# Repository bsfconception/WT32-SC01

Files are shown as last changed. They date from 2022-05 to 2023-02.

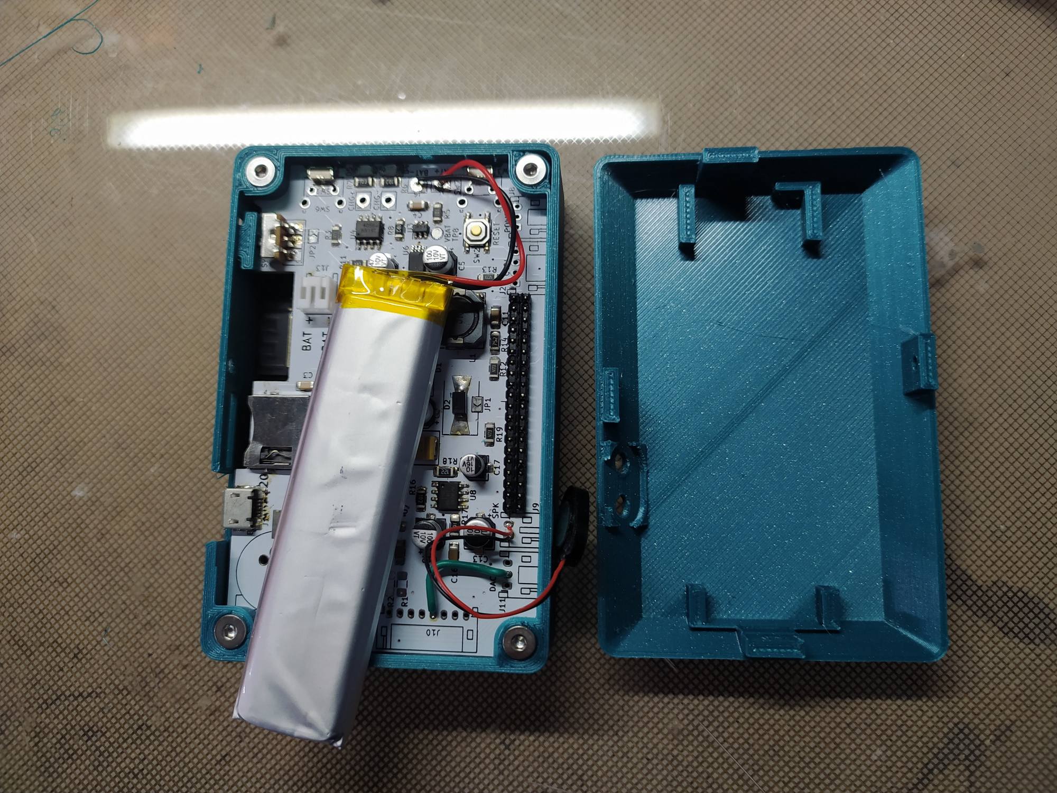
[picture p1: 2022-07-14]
Cases/V1.1/Image1.jpg

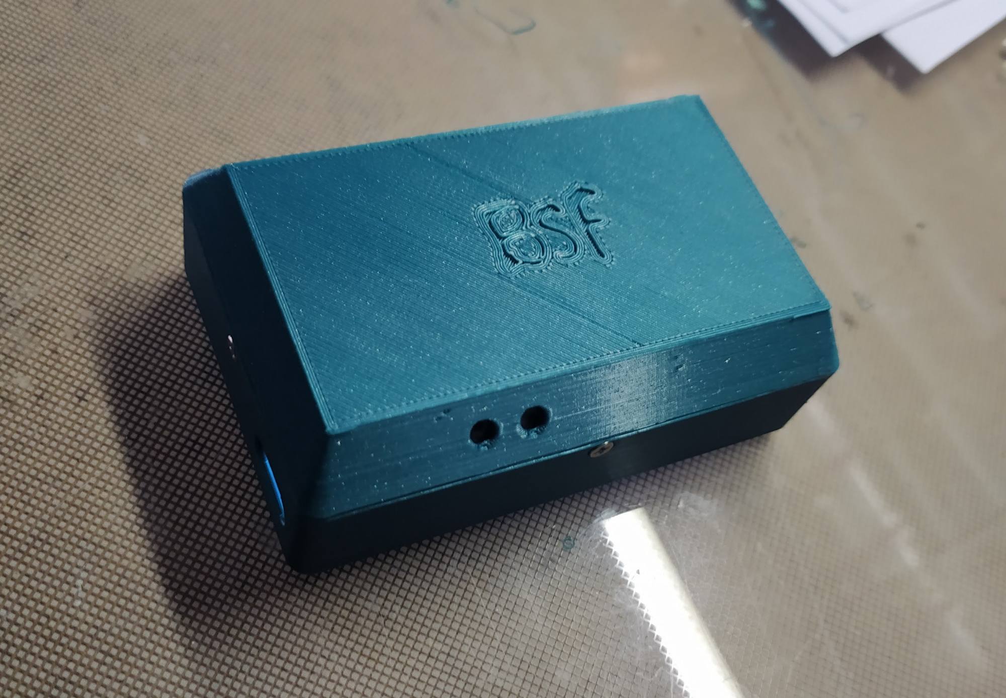
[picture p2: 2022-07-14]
Cases/V1.1/Image2.jpg

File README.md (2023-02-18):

# WT32-SC01 Extension Board V2.0

## Extension board for the WT32-SC01 Dev Kit

this board is ready to be plugged one of the WT32-SC01 from Wireless-Tag (c)
http://www.wireless-tag.com/portfolio/wt32-sc01/

It includes the following features:
- New LiPo - LiIon battery charger with overcharge and overdischarge protection
- 4 power status LEDs (0 to 100%)
- 2 push buttons with sleep and deep sleep capabilities
- DS3121M - DS3231 - PCF8563T RTC clock + backup battery - SuperCapa
- Micro SD connector
- MCP4725 DAC + LM386 Speaker amplifier 
- I2C, IO, Control and Power extension connectors
- MicroUSB connector for Li-Ion charging 
- Buzzer

The last current version is V2.0

The manufactiring files are avialable here : https://github.com/bsfconception/WT32-SC01/tree/main/Versions/V2.0
3D_CAPA

PinOut

WT32-SC01-Layout

## Demo Source Code

The demo source code tests all the expansion board feature. The testing code is provided "as is" and includes : 
- DAC setup and test
- Basic GUI with buttons and actions control
- I2C scanner
- JPEG decoder and display
- SD Card files acces control
- SPIFF files acces control
- RTC management
- Web Server with WiFi settings and control
- ...

Note : check the code to mofidy and adjust for your testing. The "Display Picture" feature loads by defaut "logo.jpg" from the SD Card
The source code is provided "as is" as an example. Some adjustments may be required in your configuration to compile

These measurements are performed using the provided test code.

## Li-Ion battery Charging Note
The battery cna be charged from several power sources
- Micro USB Connector
- Wireless IQ module
- external power plug

The WT32-SC01 USBC-C connector CANNOT be used to charge the Li-Ion battery.

### Important Notice : Power OFF the on board power supply during the programming

# Change History
- V1.0 : 
  - correction of the Beta V0.9 (bad connector positon)
- V1.1 : 
  - Micro USB connector for battery charging
  - SEL button option selection (Pull-Up or Down)
- V1.2 : 
  - Power led on the PCB
  - RF Emitter footprint
  - DS1307 footprint (less accurate, but less expensive)
  - Jumper between ESP32 pin and Audio Amp
- V2.0 : 
  - New Li-Ion charger + Bulk Power 
  - Support DS3231 - PCF8563T
  - Super Capacitor (RTC backup)
  - On Board Buzzer
  - Merge of the 2 "audio" connectors

## You want a PCB ?
You can either bluid your own with the provided manufactiring files, or purchase here :
#NOTE : the previous version are not more available. The new vervion (V2.0) is in production.

PCB Only : https://www.tindie.com/products/28469/

Assembled board : https://www.tindie.com/products/26898/



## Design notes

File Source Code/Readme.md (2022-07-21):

# Demonstration Software

The demo code is provided "as is". Is is based on personal developement and from examples retrived from sereval sources.

The intend of this software is to check the operation of the board, NOT TO PROVIDE A FINAL SOLUTION. 

## Arduino Configuration
- Version 1.8.19
- Boards Manager in "preferences":
    - https://raw.githubusercontent.com/espressif/arduino-esp32/gh-pages/package_esp32_index.json
    - http://arduino.esp8266.com/stable/package_esp8266com_index.json

## Some libraries are required to compile the code:

- name=Adafruit BusIO       url=https://github.com/adafruit/Adafruit_BusIO	        version=1.12.0
- name=Adafruit FT6206 Library      url=https://github.com/adafruit/Adafruit_FT6206_Library	        version=1.0.6
- name=Adafruit GFX Library     	url=https://github.com/adafruit/Adafruit-GFX-Library	        version=1.11.3
- name=Adafruit ILI9341	        url=https://github.com/adafruit/Adafruit_ILI9341	        version=1.5.11
- name=JPEGDecoder	        url=https://github.com/Bodmer/JPEGDecoder	        version=1.8.1
- name=lvgl	        url=https://lvgl.io	        version=8.2.0
- name=MCP4725	        url=https://github.com/RobTillaart/MCP4725	    version=0.3.3
- name=RTClib	        url=https://github.com/adafruit/RTClib	        version=2.0.3
- name=TFT_eSPI	        url=https://github.com/Bodmer/TFT_eSPI	        version=2.4.72

# Libraries customisation

Sereval modification are requied in the downloaded libraries:

## TFT_eSPI library 
has to be correctly setup for the destination board during compiling : 
A configuration file has to be created and stored in the LIB folder
C:\Users\xxxuserxxx\Documents\Arduino\libraries\TFT_eSPI
- User_Setup_Select.h
- WT32-SC01-User_Setup.h

## LVGL
the following file 
    C:\Users\XXXX\Documents\Arduino\libraries\lvgl\lv_conf_template.h
    must be renamed and copied to 
    C:\Users\XXXX\Documents\Arduino\libraries\lvgl\src\lv_conf.h

# Test code 
Two examples are provided : 
- WT32_BSF_LVGL_Demo : code based on the previous but adding the LVGL graphical interface. A setting enables or disables the LVGL features

Ensure that you enable the SPIFF features when compiling and uploading the code on the ESP32

## Notes
Somes guides have been helpfull to make it run
- https://blog.csdn.net/weixin_44007534/article/details/115224595
- https://daumemo.com/how-to-use-lvgl-library-on-arduino-with-an-esp-32-and-spi-lcd/
- https://github.com/sukesh-ak/LVGL8-WT32-SC01-Arduino

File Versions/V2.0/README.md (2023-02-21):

# WT32-SC01 Extension Board V2.0

## Extension board for the WT32-SC01 Dev Kit

this board is ready to be plugged one of the WT32-SC01 from Wireless-Tag (c)
http://www.wireless-tag.com/portfolio/wt32-sc01/

It includes the following features:
- New LiPo - LiIon battery charger with overcharge and overdischarge protection
- 4 power status LEDs (0 to 100%)
- 2 push buttons with sleep and deep sleep capabilities
- DS3121M - DS3231 - PCF8563T RTC clock + backup battery - SuperCapa
- Micro SD connector
- MCP4725 DAC + LM386 Speaker amplifier 
- I2C, IO, Control and Power extension connectors
- MicroUSB connector for Li-Ion charging 
- Buzzer

The last current version is V2.0

The manufactiring files are avialable here : https://github.com/bsfconception/WT32-SC01/tree/main/Versions/V2.0
3D_CAPA

PinOut

WT32-SC01-Layout

## Note about he IP5306 Integrated Power Bank SOC
The datasheet contains an error about the usage of the POWER key : 
- Short Pulse : POWER ON
- 2 Short Pulses : POWER OFF
- Long Pulse (>2sec) : Toggle Torch Light

## Demo Source Code

The demo source code tests all the expansion board feature. The testing code is provided "as is" and includes : 
- DAC setup and test
- IO4 PMW output if NO DEC is present
- Basic GUI with buttons and actions control
- I2C scanner
- JPEG decoder and display
- SD Card files acces control
- SPIFF files acces control
- DS3231 / DS3232 / PCF8563 RTC chip management
- Web Server with WiFi settings and control
- ...

Note : check the code to mofidy and adjust for your testing. The "Display Picture" feature loads by defaut "logo.jpg" from the SD Card
The source code is provided "as is" as an example. Some adjustments may be required in your configuration to compile

These measurements are performed using the provided test code.

## Li-Ion battery Charging Note
The battery cna be charged from several power sources
- Micro USB Connector
- Wireless IQ module
- external power plug

The WT32-SC01 USBC-C connector CANNOT be used to charge the Li-Ion battery.

### Important Notice : Power OFF the on board power supply during the programming

# Change History
- V1.0 : 
  - correction of the Beta V0.9 (bad connector positon)
- V1.1 : 
  - Micro USB connector for battery charging
  - SEL button option selection (Pull-Up or Down)
- V1.2 : 
  - Power led on the PCB
  - RF Emitter footprint
  - DS1307 footprint (less accurate, but less expensive)
  - Jumper between ESP32 pin and Audio Amp
- V2.0 : 
  - New Li-Ion charger + Bulk Power 
  - Support DS3231 - PCF8563T
  - Super Capacitor (RTC backup)
  - On Board Buzzer
  - Merge of the 2 "audio" connectors

## You want a PCB ?
You can either bluid your own with the provided manufactiring files, or purchase here :
#NOTE : the previous version are not more available. The new vervion (V2.0) is in production.

PCB Only : https://www.tindie.com/products/28469/

Assembled board : https://www.tindie.com/products/26898/



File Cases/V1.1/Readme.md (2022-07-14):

New example of 3D printed enclosure for the WT32-SC01 + Extension Board






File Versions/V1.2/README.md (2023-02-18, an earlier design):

# WT32-SC01 Extension Board V1.2

## Extension board for the WT32-SC01 Dev Kit

this board is ready to be plugged one of the WT32-SC01 from Wireless-Tag (c)
http://www.wireless-tag.com/portfolio/wt32-sc01/

It includes the following features:
- LiPo - LiIon battery charger with overcharge and overdischarge protection
- Charging status LEDs
- 2 push buttons with sleep and deep sleep capabilities
- DS3121M RTC clock + backup battery (OR)
- DS1307 + Crystal + backup battery
- Micro SD connector
- MCP4725 DAC + LM386 Speaker amplifier 
- I2C, IO, Control and Power extension connectors
- Battery Voltage feedback to the ESP
- MicroUSB connector for Li-Ion charging 
- Power LED (Note : the 5V power LED is lightned only when the WT32 SC01 main board is plugged on)
- RF Transmitter 3 pins connector

View

PCB Pinout 
WT32-SC01 Pinout_Red

PCB Assembly
WT32-SC01 V1 2_Assembly

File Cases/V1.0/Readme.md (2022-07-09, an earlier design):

You'll find here a example of 3D printed box and holder to insert the WT32

Below some illustration of the mounting and results : 

Solter 3mm inserts on the WT32 main PCB :


3D printed box :


Assembling the wirelass charger:


Adding the 1500mAh LiIon battery:




Testing the charger


The Holder 3D view (Laser cut acrylic sheet)

WT32_SC01_V0

The SVG file is provided as well in the "Holder" folder

The Wireless charger is based on these modules :
H4e3d569b123046619c432bc34786523bI
and 
H26b5287e51b44ef6bf7de7b725d772dfk
Available also on AliExpress

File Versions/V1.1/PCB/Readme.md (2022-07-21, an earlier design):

# Jumpers Options

## JP3 : set the MCP4725 address
According to the soldered bridge, the I2C addresse will change.

Jumper1

This example may change according to the manufacturer's specifications

## JP4 : SEL button default value

- Configuration 1 (default) : the Default value for SEL is '0'

R19 Set

Jumper2_0

- Configuration 2  : the Default value for SEL is '1'

R19 Remove

Jumper2_1

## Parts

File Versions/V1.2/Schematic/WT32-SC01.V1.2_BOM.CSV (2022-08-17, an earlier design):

Reference(s) | Value | Footprint
BT1 | CR1220 | Livrary:CR1220_SMD
C1 | 100nF | Capacitor_SMD:C_1206_3216Metric_Pad1.42x1.75mm_HandSolder
C2 | 10uF | Capacitor_SMD:CP_Elec_4x4.5
C3 | 100nF | Capacitor_SMD:C_1206_3216Metric_Pad1.42x1.75mm_HandSolder
C4 | 100nF | Capacitor_SMD:C_1206_3216Metric_Pad1.42x1.75mm_HandSolder
C5 | 100uF | Capacitor_SMD:CP_Elec_5x5.3
C6 | 470uF | Capacitor_Tantalum_SMD:CP_EIA-7360-38_Kemet-E
C7 | 100uF | Capacitor_SMD:CP_Elec_5x5.3
C8 | 100uF | Capacitor_SMD:CP_Elec_5x5.3
C9 | 470uF | Capacitor_Tantalum_SMD:CP_EIA-7360-38_Kemet-E
C10 | 47uF | Capacitor_SMD:CP_Elec_4x4.5
C11 | 100nF | Capacitor_SMD:C_1206_3216Metric_Pad1.42x1.75mm_HandSolder
C12 | 100uF | Capacitor_SMD:CP_Elec_5x5.3
C13 | 220uF | Capacitor_SMD:CP_Elec_5x5.3
C14 | 100nF | Capacitor_SMD:C_1206_3216Metric_Pad1.42x1.75mm_HandSolder
C15 | 220uF | Capacitor_SMD:CP_Elec_5x5.3
C16 | 47nF | Capacitor_SMD:C_1206_3216Metric_Pad1.42x1.75mm_HandSolder
C17 | 10uF | Capacitor_SMD:CP_Elec_4x4.5
C18 | 220uF | Capacitor_Tantalum_SMD:CP_EIA-7360-38_Kemet-E_Pad2.25x4.25mm_HandSolder
C19 | 100nF | Capacitor_SMD:C_1206_3216Metric_Pad1.42x1.75mm_HandSolder
D1 | SR540 | Diode_SMD:D_SMA
D2 | 1N4004 | Diode_SMD:D_SMA
D3 | PWR | LED_SMD:LED_1206_3216Metric_Pad1.42x1.75mm_HandSolder
D4 | STBY | LED_SMD:LED_1206_3216Metric_Pad1.42x1.75mm_HandSolder
D5 | CHRG | LED_SMD:LED_1206_3216Metric_Pad1.42x1.75mm_HandSolder
J1 | SD_Card | Livrary:TF_SDCard
J2 | CTRL | Connector_JST:JST_PH_S4B-PH-K_1x04_P2.00mm_Horizontal
J3 | I2C | Connector_JST:JST_PH_S4B-PH-K_1x04_P2.00mm_Horizontal
J8 | POWER | Connector_JST:JST_PH_S3B-PH-K_1x03_P2.00mm_Horizontal
J9 | SPK | Connector_JST:JST_PH_S2B-PH-K_1x02_P2.00mm_Horizontal
J10 | GPIO | Connector_JST:JST_PH_S8B-PH-K_1x08_P2.00mm_Horizontal
J11 | DAC | Connector_JST:JST_PH_S3B-PH-K_1x03_P2.00mm_Horizontal
J12 | I2C | Connector_JST:JST_SH_SM04B-SRSS-TB_1x04-1MP_P1.00mm_Horizontal
J13 | BAT | Connector_JST:JST_PH_S2B-PH-K_1x02_P2.00mm_Horizontal
J14 | USB_B_Micro | Livrary:USB_Micro-B
L1 | 3u3 | Inductor_SMD:L_10.4x10.4_H4.8
R1 | 47K* - NOT REQUIRED | Resistor_SMD:R_1206_3216Metric_Pad1.42x1.75mm_HandSolder
R2 | 47K* - NOT REQUIRED | Resistor_SMD:R_1206_3216Metric_Pad1.42x1.75mm_HandSolder
R3 | 47K | Resistor_SMD:R_1206_3216Metric_Pad1.42x1.75mm_HandSolder
R4 | 75K | Resistor_SMD:R_1206_3216Metric_Pad1.42x1.75mm_HandSolder
R5 | 100 | Resistor_SMD:R_1206_3216Metric_Pad1.42x1.75mm_HandSolder
R6 | 1K | Resistor_SMD:R_1206_3216Metric_Pad1.42x1.75mm_HandSolder
R7 | 1K | Resistor_SMD:R_1206_3216Metric_Pad1.42x1.75mm_HandSolder
R8 | 1K | Resistor_SMD:R_1206_3216Metric_Pad1.42x1.75mm_HandSolder
R9 | 10K | Resistor_SMD:R_1206_3216Metric_Pad1.42x1.75mm_HandSolder
R10 | 33K | Resistor_SMD:R_1206_3216Metric_Pad1.42x1.75mm_HandSolder
R11 | 1K8 | Resistor_SMD:R_1206_3216Metric_Pad1.42x1.75mm_HandSolder
R12 | 47K | Resistor_SMD:R_1206_3216Metric_Pad1.42x1.75mm_HandSolder
R13 | 47K | Resistor_SMD:R_1206_3216Metric_Pad1.42x1.75mm_HandSolder
R14 | 7K5 | Resistor_SMD:R_1206_3216Metric_Pad1.42x1.75mm_HandSolder
R15 | 20K | Resistor_SMD:R_1206_3216Metric_Pad1.42x1.75mm_HandSolder
R16 | 1K | Resistor_SMD:R_1206_3216Metric_Pad1.42x1.75mm_HandSolder
R17 | 10 | Resistor_SMD:R_1206_3216Metric_Pad1.42x1.75mm_HandSolder
R18 | 1K2 | Resistor_SMD:R_1206_3216Metric_Pad1.42x1.75mm_HandSolder
R19 | 47K | Resistor_SMD:R_1206_3216Metric_Pad1.42x1.75mm_HandSolder
R20 | 1K | Resistor_SMD:R_1206_3216Metric_Pad1.42x1.75mm_HandSolder
R21 | 10K | Resistor_SMD:R_1206_3216Metric_Pad1.42x1.75mm_HandSolder
SW1 | WAKE | Livrary:SW_PUSH_TS_1224W
SW2 | RESET | Livrary:SW_Push_1P1T_Mini4x4x1.5
SW3 | SEL | Livrary:SW_PUSH_TS_1224W
SW4 | SWITCH | Livrary:SW_MSK_01S
SW5 | SWITCH | Livrary:SPDT_Small
SW6 | WAKE | Button_Switch_THT:SW_Tactile_SPST_Angled_PTS645Vx58-2LFS
SW7 | SEL | Button_Switch_THT:SW_Tactile_SPST_Angled_PTS645Vx58-2LFS
U1 | DS3231M | Package_SO:SOIC-16W_7.5x10.3mm_P1.27mm
U2 | WT32-SC01 | Livrary:WS32-SC01-H
U3 | DW01x | Package_TO_SOT_SMD:TSOT-23-6
U4 | TP4056 | Livrary:SOP-8_EP
U5 | FP6298 | Package_SO:SOIC-8-1EP_3.9x4.9mm_P1.27mm_EP2.29x3mm
U6 | FS8205 | Package_SO:TSSOP-8_4.4x3mm_P0.65mm
U7 | MCP4725-DAC7571 | Package_TO_SOT_SMD:SOT-23-6
U8 | LM386 | Package_SO:SOIC-8_3.9x4.9mm_P1.27mm
U9 | TX | Livrary:TX50
U10 | DS1307Z+ | Package_SO:SOIC-8_3.9x4.9mm_P1.27mm
Y1 | 32KHz | Crystal:Crystal_C26-LF_D2.1mm_L6.5mm_Horizontal_1EP_style2
Collated Components:
Qty | Reference(s) | Value | Footprint
1 | BT1 | CR1220 | Livrary:CR1220_SMD
6 | C1, C3, C4, C11, C14, C19 | 100nF | Capacitor_SMD:C_1206_3216Metric_Pad1.42x1.75mm_HandSolder
2 | C2, C17 | 10uF | Capacitor_SMD:CP_Elec_4x4.5
6 | C5, C7, C8, C12,C13, C15 | 100uF | Capacitor_SMD:CP_Elec_5x5.3
3 | C6, C9,C18 | 470uF | Capacitor_Tantalum_SMD:CP_EIA-7360-38_Kemet-E
1 | C10 | 47uF | Capacitor_SMD:CP_Elec_4x4.5
1 | C16 | 47nF | Capacitor_SMD:C_1206_3216Metric_Pad1.42x1.75mm_HandSolder
1 | D1 | SR540 | Diode_SMD:D_SMA
1 | D2 | 1N4004 | Diode_SMD:D_SMA
1 | D3 | PWR | LED_SMD:LED_1206_3216Metric_Pad1.42x1.75mm_HandSolder
1 | D4 | STBY | LED_SMD:LED_1206_3216Metric_Pad1.42x1.75mm_HandSolder
1 | D5 | CHRG | LED_SMD:LED_1206_3216Metric_Pad1.42x1.75mm_HandSolder
1 | J1 | SD_Card | Livrary:TF_SDCard
1 | J2 | CTRL | Connector_JST:JST_PH_S4B-PH-K_1x04_P2.00mm_Horizontal
1 | J3 | I2C | Connector_JST:JST_PH_S4B-PH-K_1x04_P2.00mm_Horizontal
1 | J8 | POWER | Connector_JST:JST_PH_S3B-PH-K_1x03_P2.00mm_Horizontal
1 | J9 | SPK | Connector_JST:JST_PH_S2B-PH-K_1x02_P2.00mm_Horizontal
1 | J10 | GPIO | Connector_JST:JST_PH_S8B-PH-K_1x08_P2.00mm_Horizontal
1 | J11 | DAC | Connector_JST:JST_PH_S3B-PH-K_1x03_P2.00mm_Horizontal
1 | J12 | I2C | Connector_JST:JST_SH_SM04B-SRSS-TB_1x04-1MP_P1.00mm_Horizontal
1 | J13 | BAT | Connector_JST:JST_PH_S2B-PH-K_1x02_P2.00mm_Horizontal
1 | J14 | USB_B_Micro | Livrary:USB_Micro-B
1 | L1 | 3u3 | Inductor_SMD:L_10.4x10.4_H4.8
2 | R1, R2 - NOT REQUIRED | 47K* | Resistor_SMD:R_1206_3216Metric_Pad1.42x1.75mm_HandSolder
4 | R3, R12, R13, R19 | 47K | Resistor_SMD:R_1206_3216Metric_Pad1.42x1.75mm_HandSolder
1 | R4 | 75K | Resistor_SMD:R_1206_3216Metric_Pad1.42x1.75mm_HandSolder
1 | R5 | 100 | Resistor_SMD:R_1206_3216Metric_Pad1.42x1.75mm_HandSolder
5 | R6, R7, R8, R16, R20 | 1K | Resistor_SMD:R_1206_3216Metric_Pad1.42x1.75mm_HandSolder
2 | R9, R21 | 10K | Resistor_SMD:R_1206_3216Metric_Pad1.42x1.75mm_HandSolder
1 | R10 | 33K | Resistor_SMD:R_1206_3216Metric_Pad1.42x1.75mm_HandSolder
1 | R11 | 1K8 | Resistor_SMD:R_1206_3216Metric_Pad1.42x1.75mm_HandSolder
1 | R14 | 7K5 | Resistor_SMD:R_1206_3216Metric_Pad1.42x1.75mm_HandSolder
1 | R15 | 20K | Resistor_SMD:R_1206_3216Metric_Pad1.42x1.75mm_HandSolder
1 | R17 | 10 | Resistor_SMD:R_1206_3216Metric_Pad1.42x1.75mm_HandSolder
1 | R18 | 1K2 | Resistor_SMD:R_1206_3216Metric_Pad1.42x1.75mm_HandSolder
1 | SW1 | WAKE | Livrary:SW_PUSH_TS_1224W
1 | SW2 | RESET | Livrary:SW_Push_1P1T_Mini4x4x1.5
1 | SW3 | SEL | Livrary:SW_PUSH_TS_1224W
1 | SW4 | SWITCH | Livrary:SW_MSK_01S
1 | SW5 | SWITCH | Livrary:SPDT_Small
1 | SW6 | WAKE | Button_Switch_THT:SW_Tactile_SPST_Angled_PTS645Vx58-2LFS
1 | SW7 | SEL | Button_Switch_THT:SW_Tactile_SPST_Angled_PTS645Vx58-2LFS
1 | U1 | DS3231M | Package_SO:SOIC-16W_7.5x10.3mm_P1.27mm
1 | U2 | WT32-SC01 | Livrary:WS32-SC01-H
1 | U3 | DW01x | Package_TO_SOT_SMD:TSOT-23-6
1 | U4 | TP4056 | Livrary:SOP-8_EP
1 | U5 | FP6298 | Package_SO:SOIC-8-1EP_3.9x4.9mm_P1.27mm_EP2.29x3mm
1 | U6 | FS8205 | Package_SO:TSSOP-8_4.4x3mm_P0.65mm
1 | U7 | MCP4725-DAC7571 | Package_TO_SOT_SMD:SOT-23-6
1 | U8 | LM386 | Package_SO:SOIC-8_3.9x4.9mm_P1.27mm
1 | U9 | TX | Livrary:TX50
1 | U10 | DS1307Z+ | Package_SO:SOIC-8_3.9x4.9mm_P1.27mm
1 | Y1 | 32KHz | Crystal:Crystal_C26-LF_D2.1mm_L6.5mm_Horizontal_1EP_style2

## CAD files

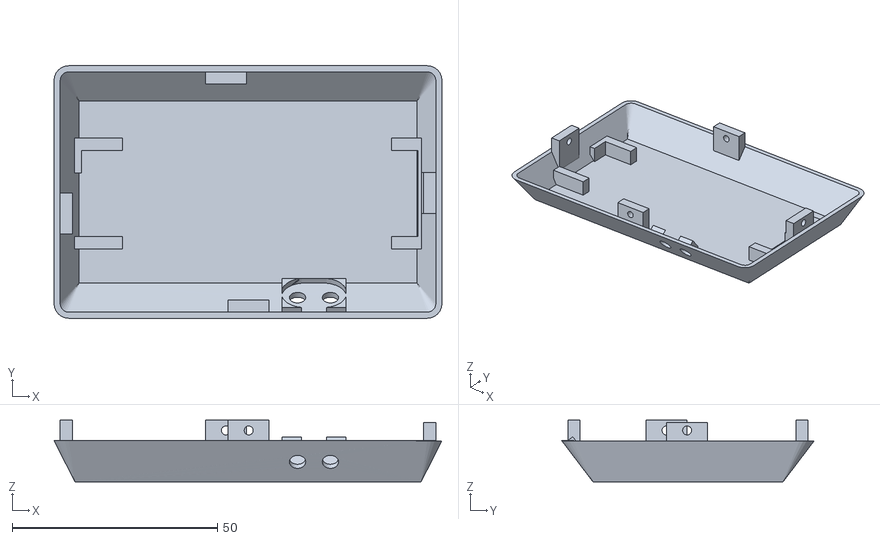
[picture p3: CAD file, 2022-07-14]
Cases/V1.1/WT_d.stl
94.6 x 61.6 x 15.0

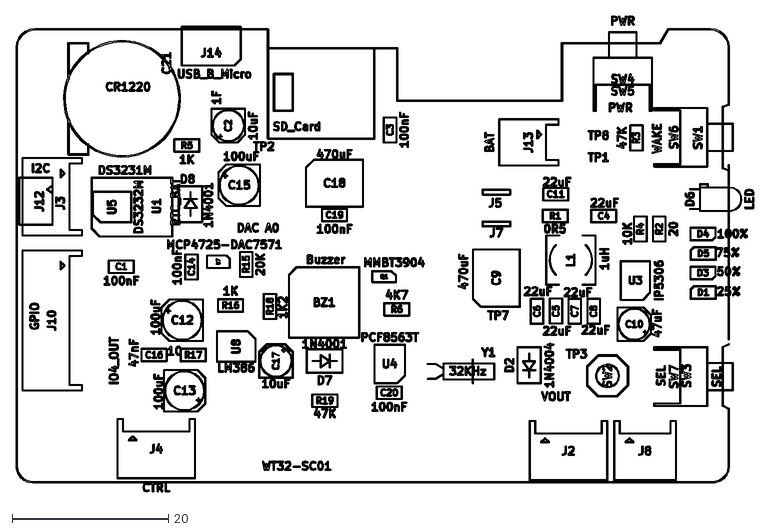
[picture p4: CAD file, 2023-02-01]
Versions/V2.0/PCB/WT32-SC01-F.Fab.dxf
94.3 x 60.9

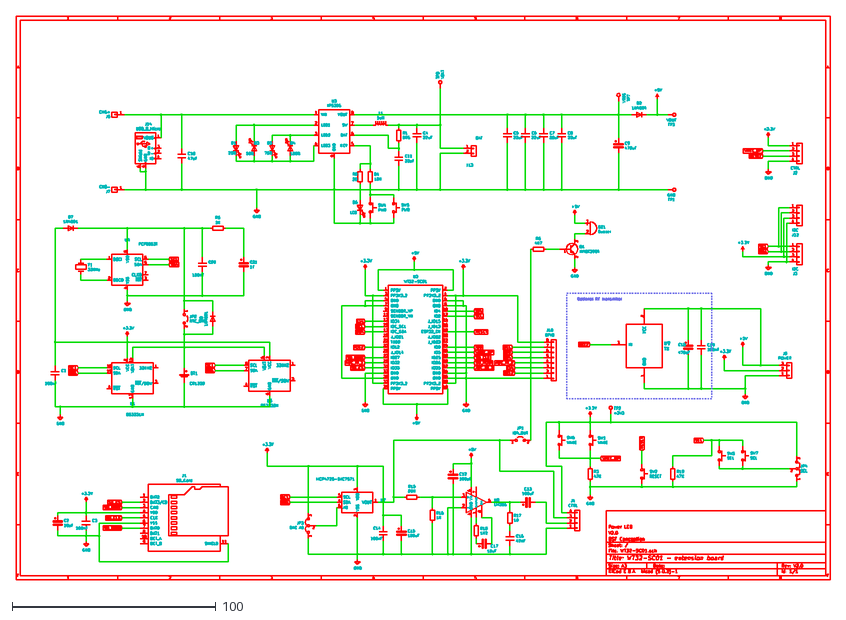
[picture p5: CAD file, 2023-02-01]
Versions/V2.0/Schematic/WT32-SC01.dxf
400.0 x 277.0

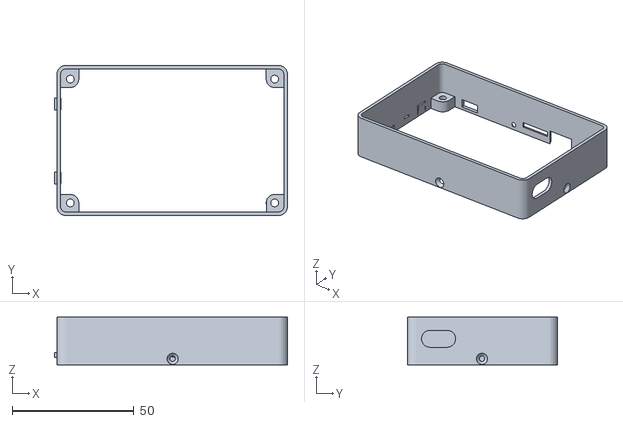
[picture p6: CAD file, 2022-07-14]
Cases/V1.1/WT_b.stl
95.6 x 61.6 x 19.6

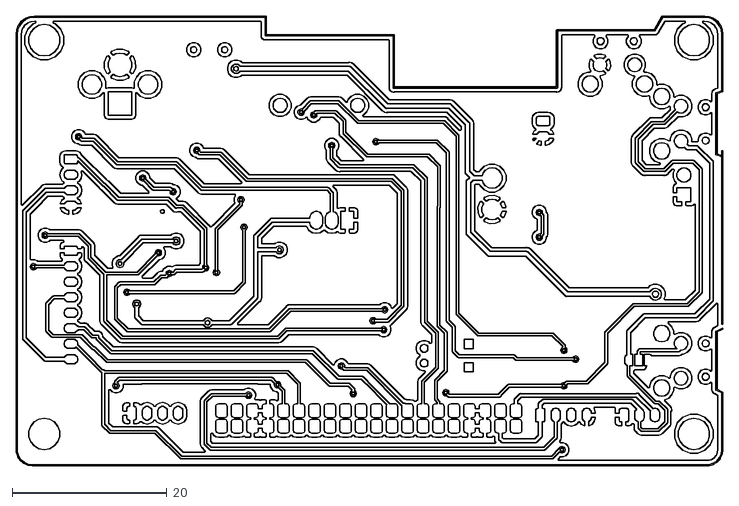
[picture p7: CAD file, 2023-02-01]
Versions/V2.0/PCB/WT32-SC01-B.Cu.dxf
91.2 x 58.1

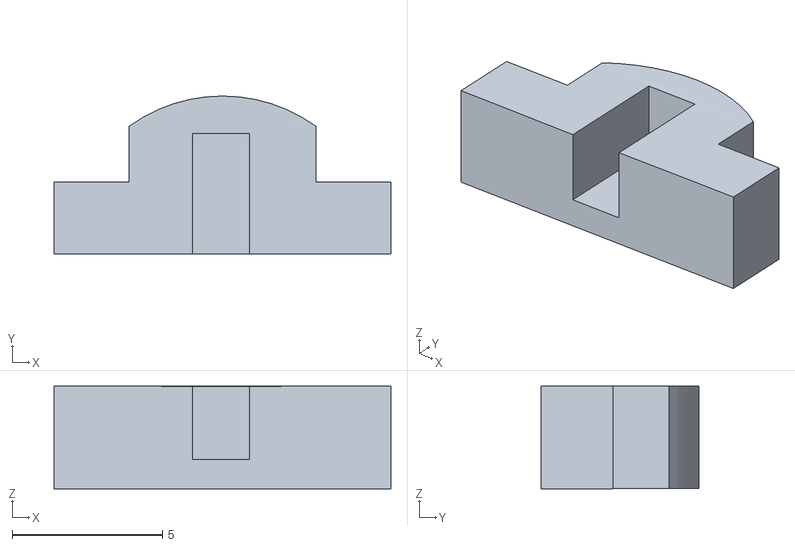
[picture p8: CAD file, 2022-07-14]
Cases/V1.1/WT_c.stl
11.2 x 5.25 x 3.42

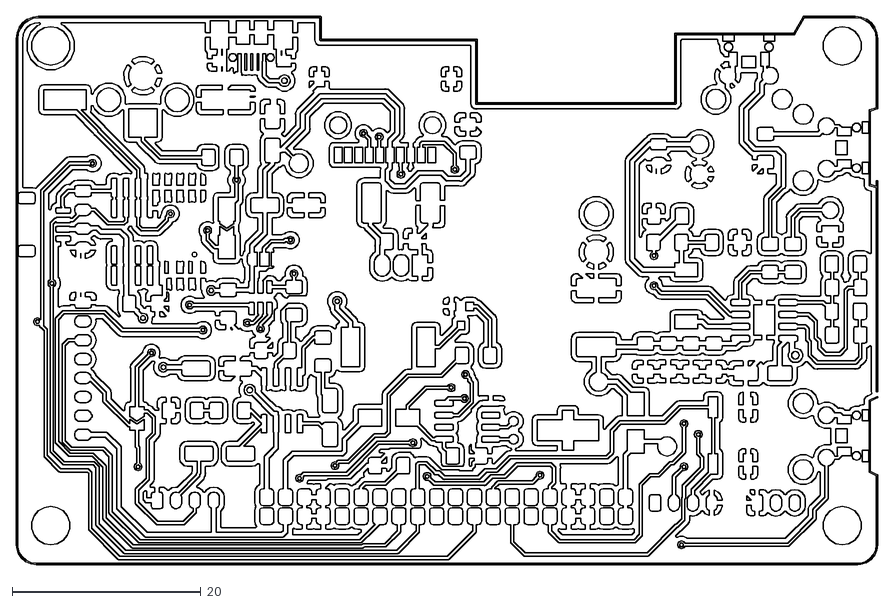
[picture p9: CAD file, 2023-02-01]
Versions/V2.0/PCB/WT32-SC01-F.Cu.dxf
91.2 x 58.1

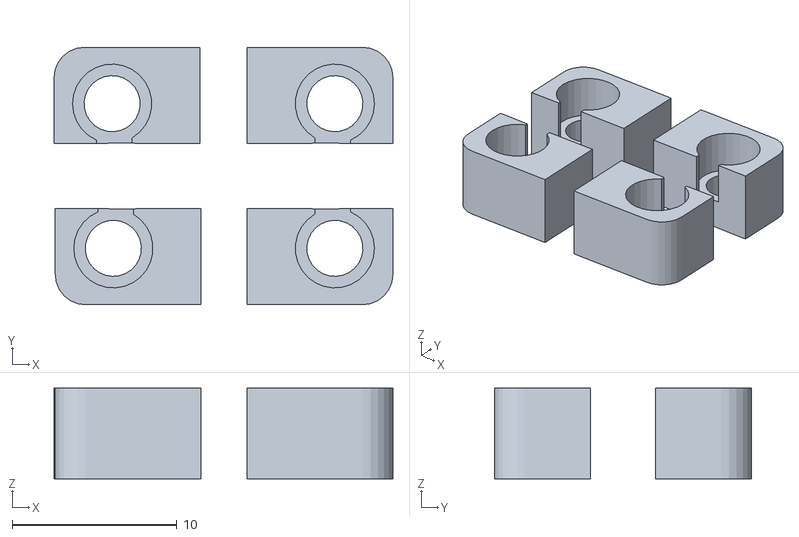
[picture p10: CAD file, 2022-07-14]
Cases/V1.1/WT_a.stl
20.5 x 15.6 x 5.50

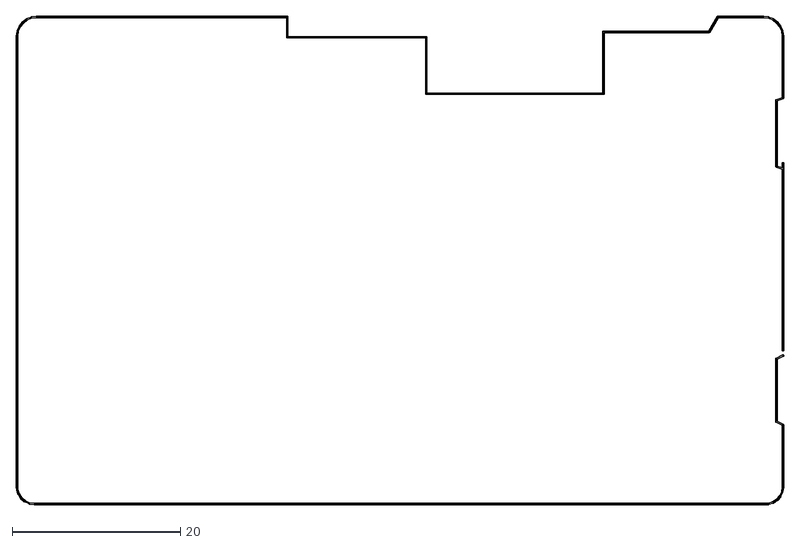
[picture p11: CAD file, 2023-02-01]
Versions/V2.0/PCB/WT32-SC01-Edge.Cuts.dxf
91.2 x 58.1

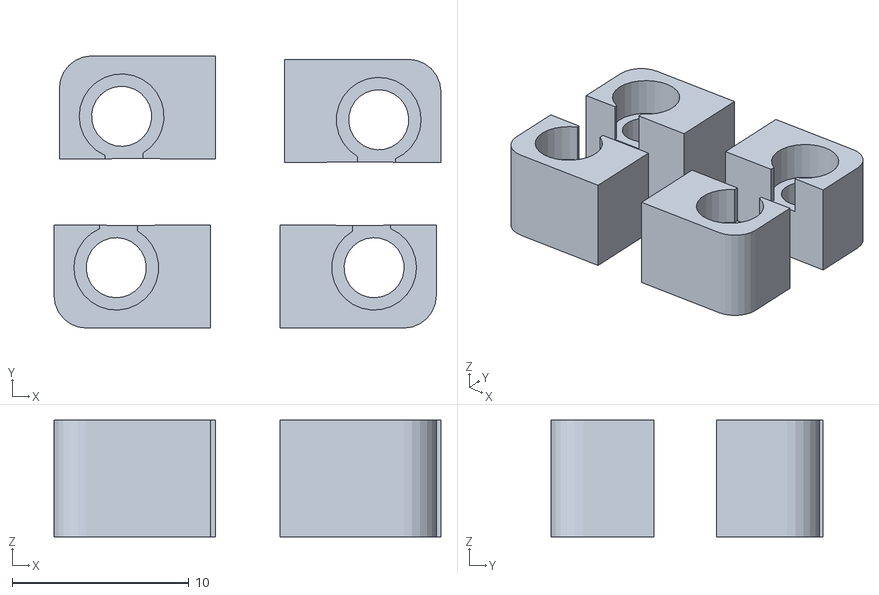
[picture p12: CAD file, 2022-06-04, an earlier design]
Cases/V1.0/3DPrint/WT32_3_corr.stl
21.9 x 15.4 x 6.60

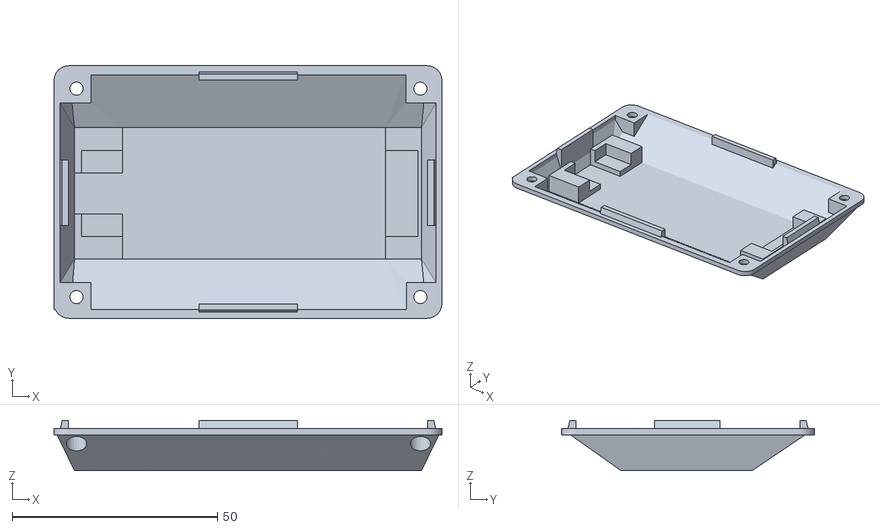
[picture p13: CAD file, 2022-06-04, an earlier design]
Cases/V1.0/3DPrint/WT32_2_corr.stl
94.6 x 61.6 x 12.2

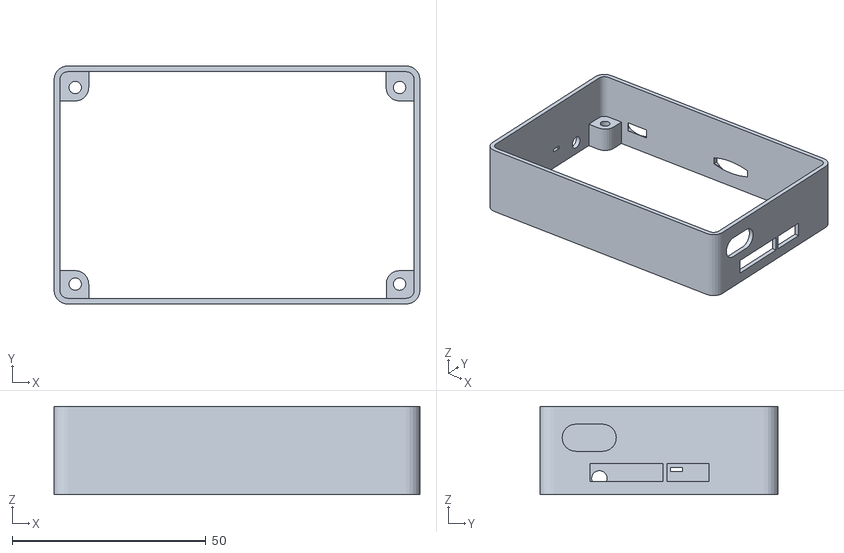
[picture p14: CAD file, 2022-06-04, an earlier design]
Cases/V1.0/3DPrint/WT32_1_corr.stl
94.6 x 61.6 x 22.8

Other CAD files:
Versions/V2.0/PCB/WT32-SC01-B.Mask.dxf
Versions/V2.0/PCB/WT32-SC01-B.Paste.dxf
Versions/V2.0/PCB/WT32-SC01-B.SilkS.dxf
Versions/V2.0/PCB/WT32-SC01-F.Mask.dxf
Versions/V2.0/PCB/WT32-SC01-F.Paste.dxf
Versions/V2.0/PCB/WT32-SC01-F.SilkS.dxf

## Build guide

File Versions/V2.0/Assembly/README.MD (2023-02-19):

# BOM #
List of components
|Item|Qty|Reference(s)|Value|
|----|----|----|----|
|1|1|BT1|CR1220 Holder|
|2|1|BZ1|SMD Buzzer|
|3|5|C1, C3, C14, C19, C20|100nF|
|4|2|C2, C17|10uF|
|5|6|C4, C5, C6, C7, C8, C11|22uF|
|6|2|C9, C18|470uF|
|7|1|C10|47uF|
|8|3|C12, C13, C15|100uF|
|9|1|C16|47nF|
|10|1|C21|1F|
|11|1|D1|25% LED|
|12|1|D2|1N4004|
|13|1|D3|50% LED|
|14|1|D4|100% LED|
|15|1|D5|75% LED|
|16|1|D6|LED|
|17|2|D7, D8|1N4001|
|18|1|J1|TF_SDCard|
|19|2|J2, J4|JST_PH_S4B-PH-K_1x04_P2.00mm_Horizontal|
|20|1|J3|JST_PH_S4B-PH-K_1x04_P2.00mm_Horizontal|
|23|1|J8|JST_PH_S3B-PH-K_1x03_P2.00mm_Horizontal|
|24|1|J10|JST_PH_S8B-PH-K_1x08_P2.00mm_Horizontal|
|25|1|J12|JST_SH_SM04B-SRSS-TB_1x04-1MP_P1.00mm_Horizontal|
|26|1|J13|JST_PH_S2B-PH-K_1x02_P2.00mm_Horizontal|
|27|1|J14|USB_B_Micro|
|32|1|L1|1uH|
|33|1|Q1|MMBT3904|
|34|1|R1|0R5|
|35|1|R2|20|
|36|2|R3, R19|47K|
|37|1|R4|10K|
|38|2|R5, R16|1K|
|39|1|R6|4K7|
|40|1|R15|20K|
|41|1|R17|10|
|42|1|R18|1K2|
|43|1|SW1|PUSH_TS_1224W|
|44|1|SW2|Push_1P1T_Mini4x4x1.5|
|45|1|SW3|PUSH_TS_1224W|
|46|1|SW4|PUSH_TS_1224W|
|47|1|SW5|SW_Tactile_SPST_Angled|
|48|1|SW6|SW_Tactile_SPST_Angled|
|49|1|SW7|SW_Tactile_SPST_Angled|
|50|1|U1|DS3231M|
|52|1|U3|IP5306|
|53|1|U4|PCF8563T|
|54|1|U5|DS3232M|
|55|1|U7|MCP4725-DAC7571|
|56|1|U8|LM386|
|58|1|Y1|32KHz|

# Mandatoru components based on options
|Reference(s)|Value|Mandatory|DS323x-CR1220|DS323x-0.5F Capa|PCF8563 CR1220|PCF8563 0.5F Capa|Buzzer|Audio Amplifier|MCP4725DAC|
|----|----|----|----|----|----|----|----|----|----|
|BT1|CR1220||Y||Y|||||
|BZ1|Buzzer||||||Y|||
|C1|100nF||Y|Y||||||
|C2|10uF|Y||||||||
|C3|100nF|Y||||||||
|C4|22uF|Y||||||||
|C5|22uF|Y||||||||
|C6|22uF|Y||||||||
|C7|22uF|Y||||||||
|C8|22uF|Y||||||||
|C9|470uF|Y||||||||
|C10|47uF|Y||||||||
|C11|22uF|Y||||||||
|C12|100uF|||||||Y||
|C13|100uF|||||||Y||
|C14|100nF||||||||Y|
|C15|100uF||||||||Y|
|C16|47nF|||||||Y||
|C17|10uF|||||||Y||
|C20|100nF||||Y|Y||||
|C21|0F5|||Y||Y||||
|D1|0.25|Y||||||||
|D2|1N4004|Y||||||||
|D3|0.5|Y||||||||
|D4|1|Y||||||||
|D5|0.75|Y||||||||
|D6|LED|Opt||||||||
|D7|1N4001|||Y|Y|Y||||
|D8|1N4001||||Y|||||
|J1|SD_Card|Y||||||||
|J2|CTRL|Y||||||||
|J3|I2C|Y||||||||
|J4|CTRL|Y||||||||
|J8|POWER|Y||||||||
|J10|GPIO|Y||||||||
|J12|I2C|Opt||||||||
|J13|BAT|Y||||||||
|J14|USB_B_Micro|Y||||||||
|JP1|IO4_OUT|||||||Closed|Open|
|JP2|RTC_BAT||Open|Closed|Open|Open|Don't Care|Don't Care|Don't Care|
|JP3|DAC A0|DAC I2C address||||||||
|JP4|SEL|Linked to R19 option||||||||
|L1|1uH|Y||||||||
|Q1|MMBT3904||||||Y|||
|R1|0R5|Y||||||||
|R3|47K|Y||||||||
|R4|10K|Y||||||||
|R5|1K|||Y||Y||||
|R6|4K7||||||Y|||
|R15|20K|||||||Y||
|R16|1K|||||||Y||
|R17|10|||||||Y||
|R18|1K2|||||||Y||
|R19|47K|Linked to JP4 option||||||||
|SW1 / SW6|WAKE|Y||||||||
|SW2|RESET|Y||||||||
|SW3 / SW7|SEL|Y||||||||
|SW4 / SW5|PWR|Y||||||||
|U1|DS3231M||Y|Y||||||
|U3|IP5306|Y||||||||
|U4|PCF8563T||||Y|Y||||
|U5|DS3232M||Y|Y||||||
|U7|MCP4725-DAC7571||||||||Y|
|U8|LM386|||||||Y||
|Y1|32KHz||||Y|Y||||

# Jumper settings
| Jumper | Picture | Description | 
| ---- | ---- | ---- |
| JP1 | JP1 | Link IO4 to Audio Amplifier | 
| JP2 | JP2 | Solder only with DS323x + 0.5FCapa | 
| JP3 | JP3_L | DAC I2C Address=0x63 | 
|  | JP3_r | DAC I2C Address=0x63 | 
| JP4 | JP4_L | Default value for SEL is '1' Remove R19 | 
|  | JP4_r | Default value for SEL is '0' Solder R19 | 

# Examples of assembled PCB #
## Base Version
Base

## Base Version + Audio Amp
opt4

## Base Version + Audio Amp + Buzzer
opt3

## Base Version + Audio Amp + Buzzer + DAC
opt2

## Base Version + Audio Amp + Buzzer + DAC + DS3232
DS3232

## Full Mounted PCB  + PCF8563 + Capacitor
Full_CAPA

## Full Mounted PCB  + PCF8563 + Battery Support
Full_CR

## Full Mounted PCB  + DS3231 + Battery Support
DS3231

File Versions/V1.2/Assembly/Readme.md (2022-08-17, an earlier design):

Here is the step by step proposal for PCB Assembly

A11
A10

Option 1 : Use DS3121 RTC Clock
A8

Option 2 : Use DS1307 + Crystal RTC Clock
A7

A6
A5
A4
A3
A2
A1

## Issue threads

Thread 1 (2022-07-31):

Assembly Instructions

JojoS62, 2022-07-31:
Thanks for the great design. I have assembled the board and just a few comments:
- the orientation for the IC U3 and U7 ist not visible in the photos or the silk screen. It would be helpful to add marks in the photos
- the connector to the display needs some special mounting. I could find it only on tindy images, after I soldered it wrong on the top side

An assembly document with these (and maybe more information) would be helpful.

Software: a configuration for platformIO would be fine also. PIO makes installing the dependencies easier.

bsfconception, 2022-08-01:
Hi,

thanks you for your inputs and suggestion.
I'll update the  PCB layout to clarify some components orientation and add
an assembly procédure.
I'll also try to work with PlatformIO  (not yet tried but it seem more and
more used).

I'm sorry about the connector confusion, if it may help you I can mail you
a new 2*20 2mm pin header to replace it (free of charge, of course)

Regards
Eric

Le dim. 31 juil. 2022 à 17:53, JojoS ***@***.***> a écrit :

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

JojoS62, 2022-08-01:
thanks, no problem with the header, I was able to desolder and fix it.
Power supply is working and I measured also charge current, but charge LED is not working. Maybe it is also turned, it has also no marks for the orientation.

bsfconception, 2022-08-01:
Hi,

here are the updated silk screen and fab screen (I guess that I forgot to
share this)
You can see the diodes direction,, IC  and confirmation of Tantale al well.

I'll cleanup the Git and Tindie because the 1.0 ans 1.1 version are out of
stock and I've manufactured a V1.2 version with small changes
I'll take into account off your comments to provide more accurate doc and
description

Regards
Eric

Le lun. 1 août 2022 à 11:23, JojoS ***@***.***> a écrit :

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

JojoS62, 2022-08-04:
thanks, this will help others too.

Closed 2022-08-04.

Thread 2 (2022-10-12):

External power supply socket in the original WT32-SC01 board

dizcza, 2022-10-12:
Hi,
do you know the socket type used in the original WT32-SC01 (without an expansion board)?
It's denoted as J0 in the datasheet but it does not mention the socket plug type which can be soldered to J0 for easy battery connection.
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

dizcza, 2022-10-12:
Looks plausible. Thanks!

dizcza, 2023-03-12:
I ordered the item you linked. The mounting pins (the bottom ones on the pic) fit perfectly with the JST SH 1mm connector but not the power pins (the upper ones). The power pins board spacing is ~1.5 mm while it should be 1.0 mm.

Don't know if it's a design flaw on their side or a Chinese feature.

Thanks anyway. I'll manually space the pins apart a bit further to fit onto the board.

Closed 2022-10-12.

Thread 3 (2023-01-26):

SD card help

cuishuang413, 2023-01-26:
Hello,

Igot one of your board and for its SD card access. I looked at your demo code and tried to implemented into my project however unable to compile.

First, I believe I need to include the following headers:
```
#include "FS.h"
#include "SD.h"
#include "SPI.h"
```

This is the code I used after some modification from yours. I bascially removed all the debug stuff. But I got 'SPI_SD' was not declared in this scope error. Can you please point me some direction? Thanks a lot!
```
int _SD_MountSDCard()
{
  //Assuming use of SPI SD card
  SPI_SD.begin(_SD_SCLK, _SD_MISO, _SD_MOSI, _SD_CS);
  if (!SD.begin(_SD_CS, SPI_SD))
  {
    Serial.println("SDCard Mount Failed");
    return(0);
  }
  else
  {
    String siz = String((uint32_t)(SD.cardSize() / 1024 / 1024)) + "MB";
    Serial.print("SDCard Mount PASS : ");
    Serial.println(siz);

  }
  return(1);
}

```

cuishuang413, 2023-01-26:
I got it.

Somhow I missed this:
`SPIClass SPI_SD(VSPI);`

Closed 2023-01-26.

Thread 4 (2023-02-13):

hardware design file

arigus, 2023-02-13:
Where i can find design files?

bsfconception, 2023-02-13:
THE PCB gerber files and schematic are available here : https://github.com/bsfconception/WT32-SC01/tree/main/Versions/V2.0
It will be updated once the new board is fully validated

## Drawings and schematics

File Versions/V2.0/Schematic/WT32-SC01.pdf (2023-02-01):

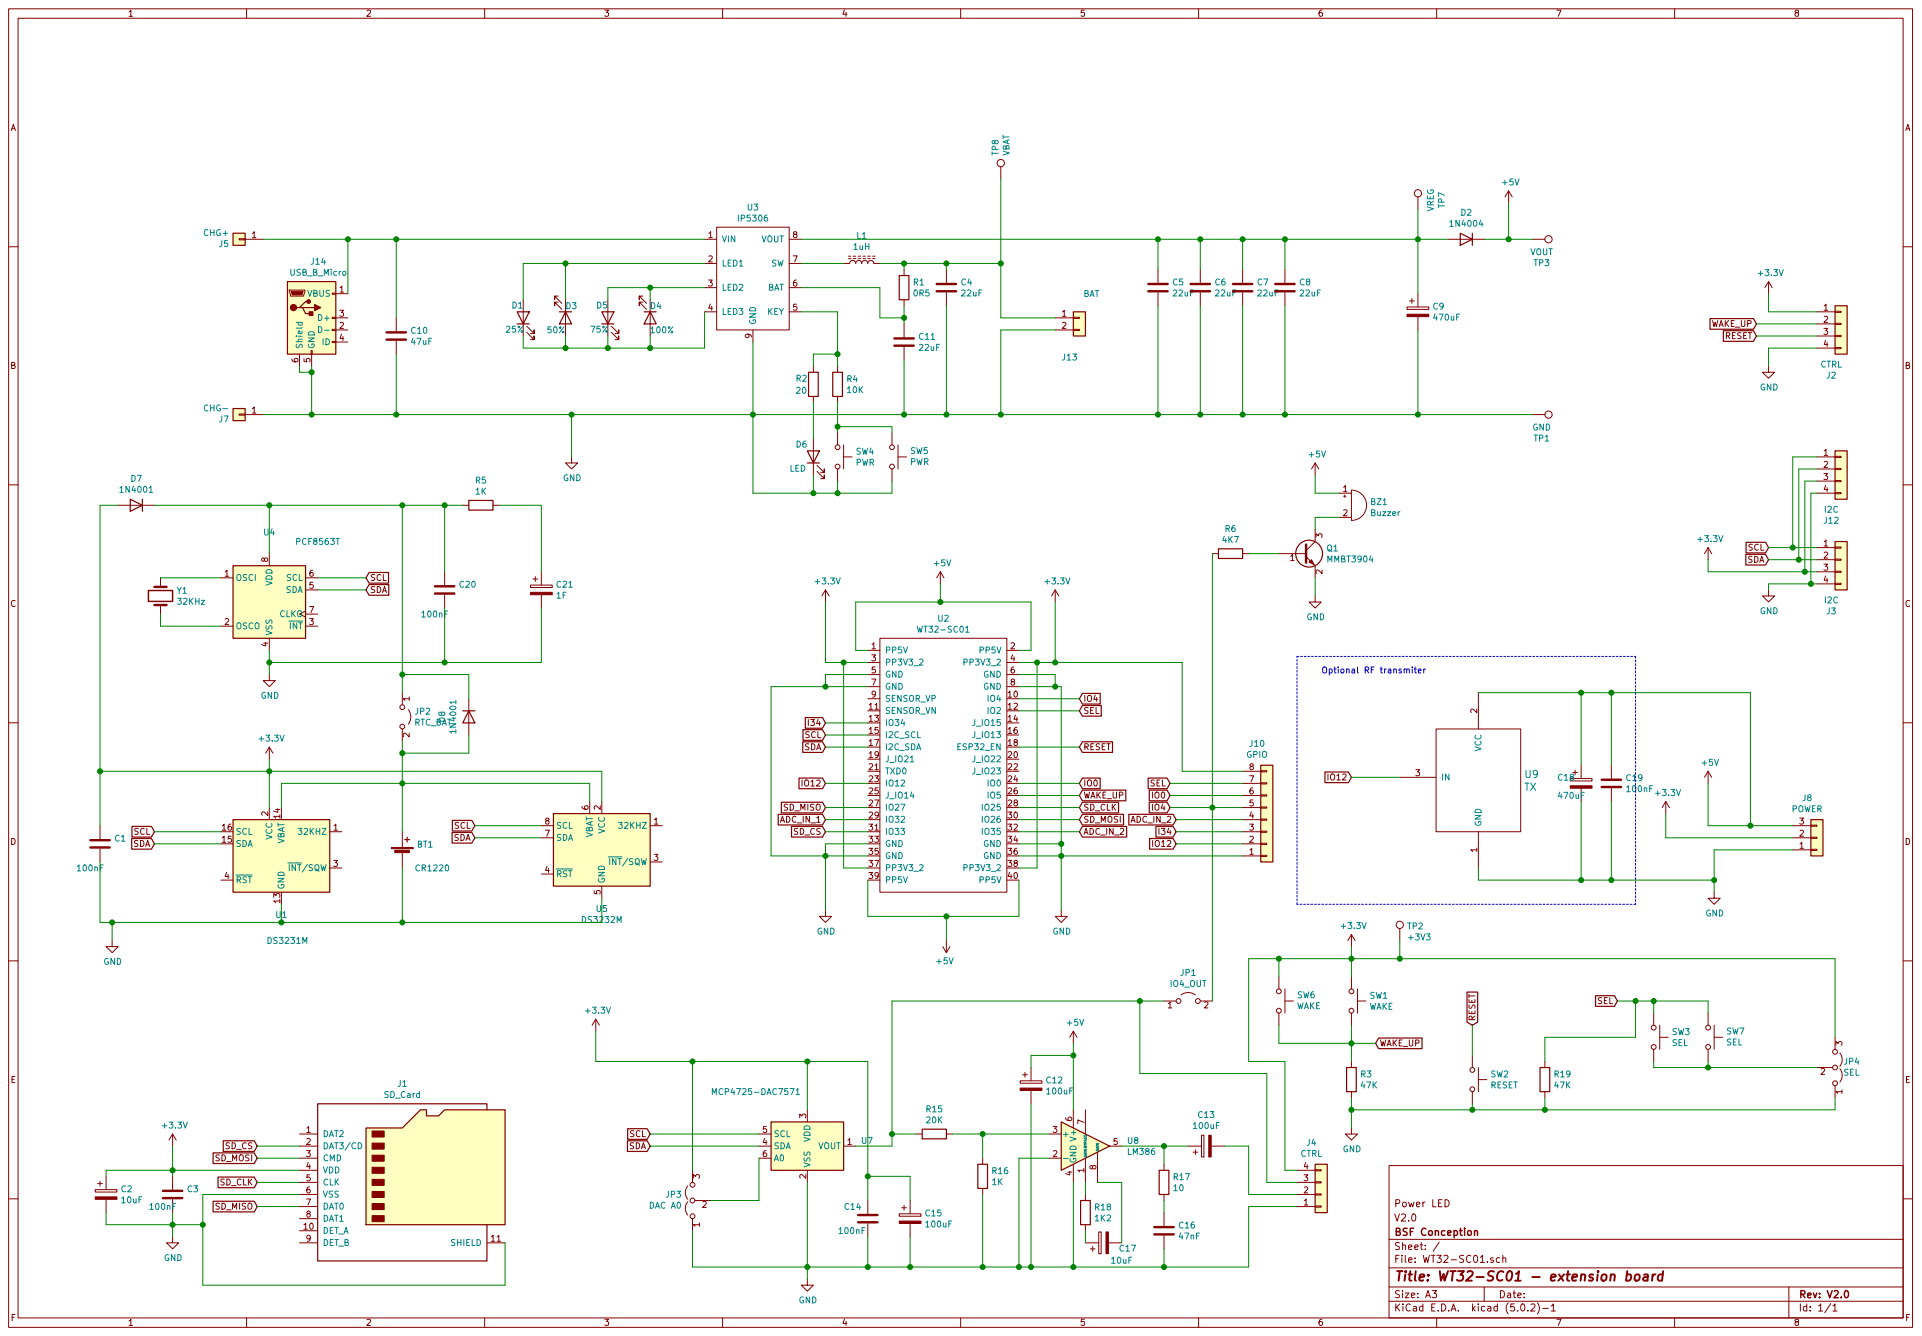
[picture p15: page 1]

4 SDA 5 SCL 6 CLKO 7 VDD

File: WT32-SC01.sch Sheet: / BSF Conception V2.0 Power LED

Id: 1/1 Title: WT32-SC01 - extension board

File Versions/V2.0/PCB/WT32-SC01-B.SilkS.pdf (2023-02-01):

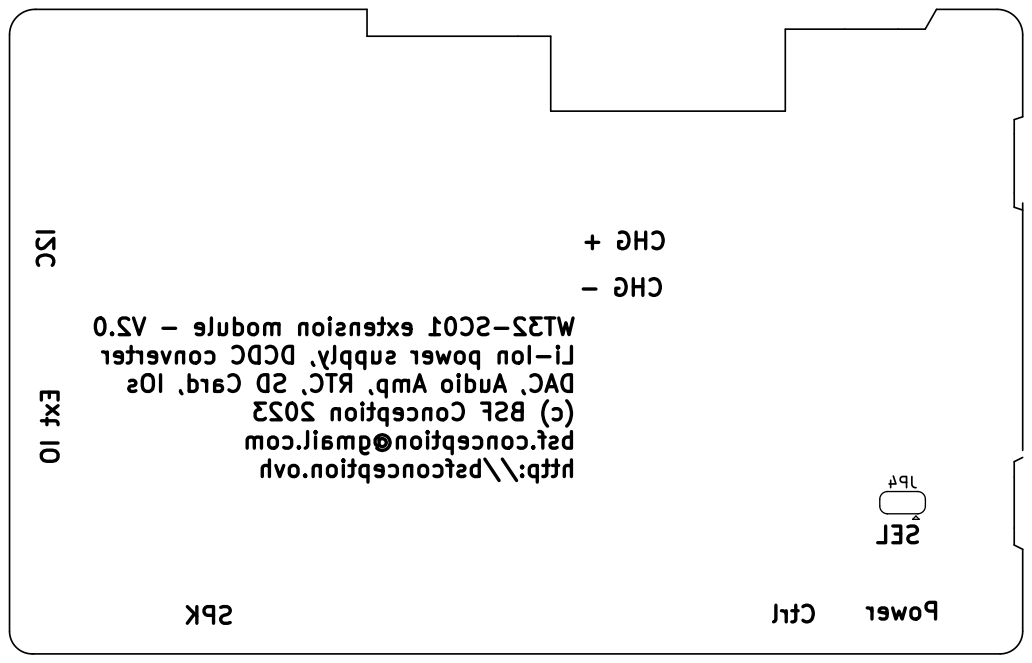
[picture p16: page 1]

SPK Ctrl Power CHG - CHG + SEL WT32-SC01 extension module - V2.0 Li-Ion power supply, DCDC converter

DAC, Audio Amp, RTC, SD Card, IOs

bsf.conception@gmail.com

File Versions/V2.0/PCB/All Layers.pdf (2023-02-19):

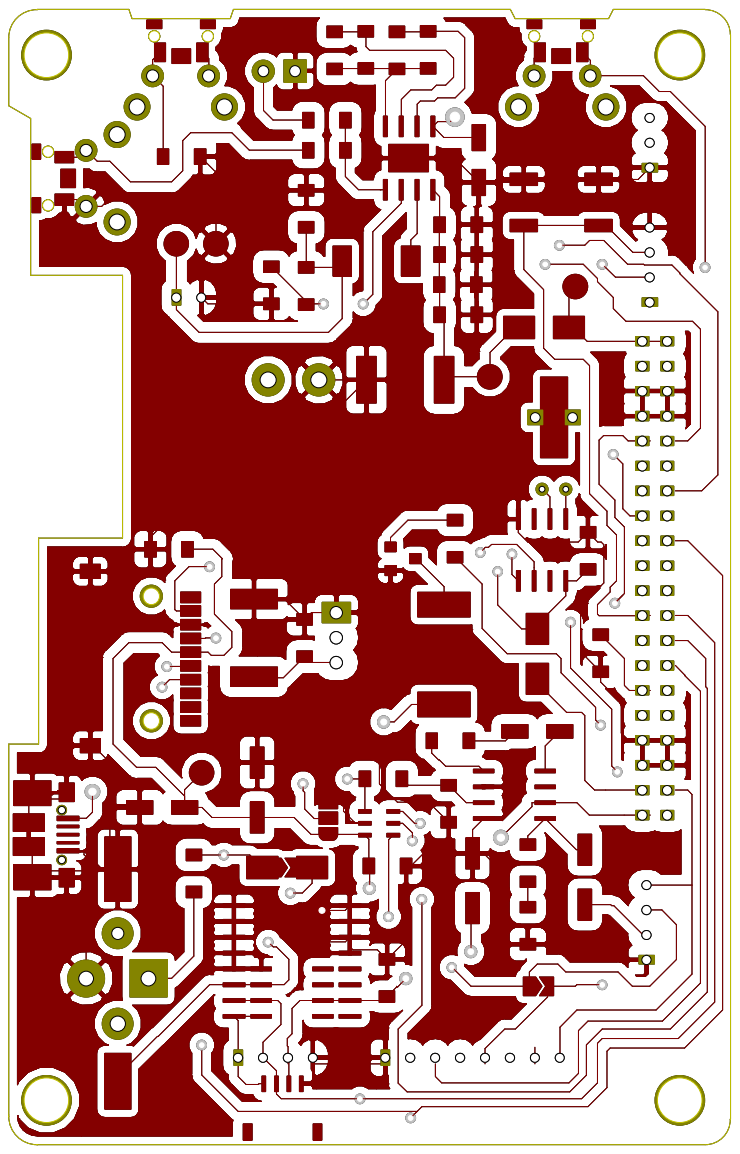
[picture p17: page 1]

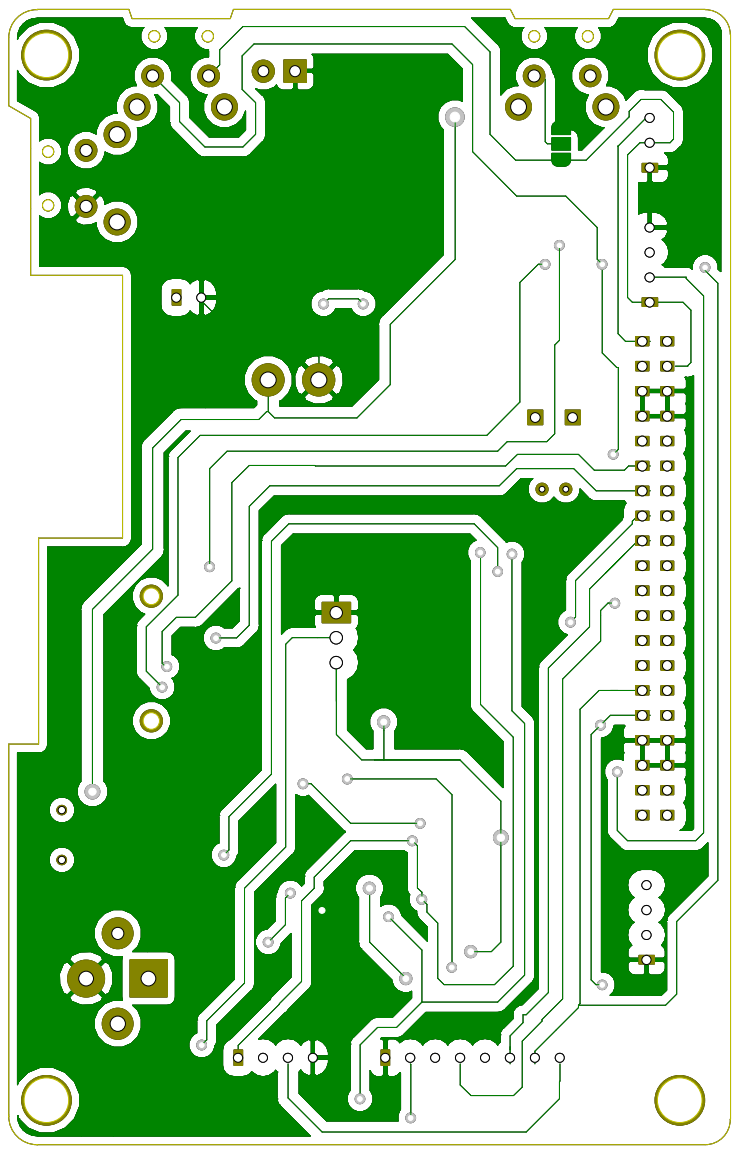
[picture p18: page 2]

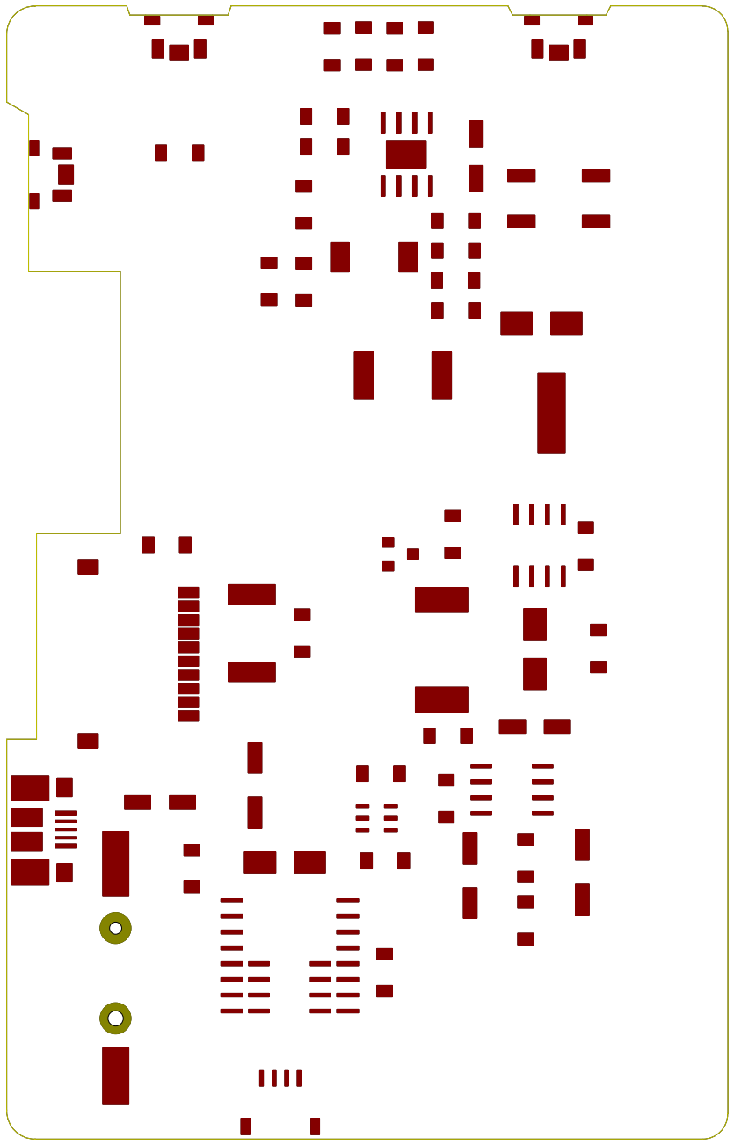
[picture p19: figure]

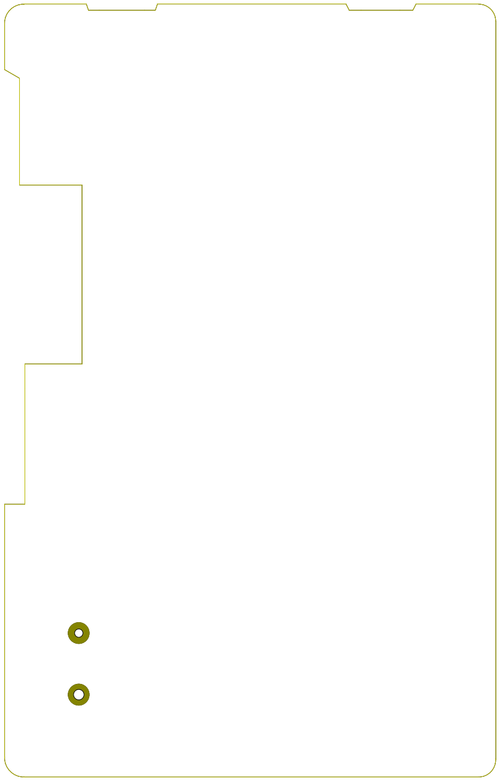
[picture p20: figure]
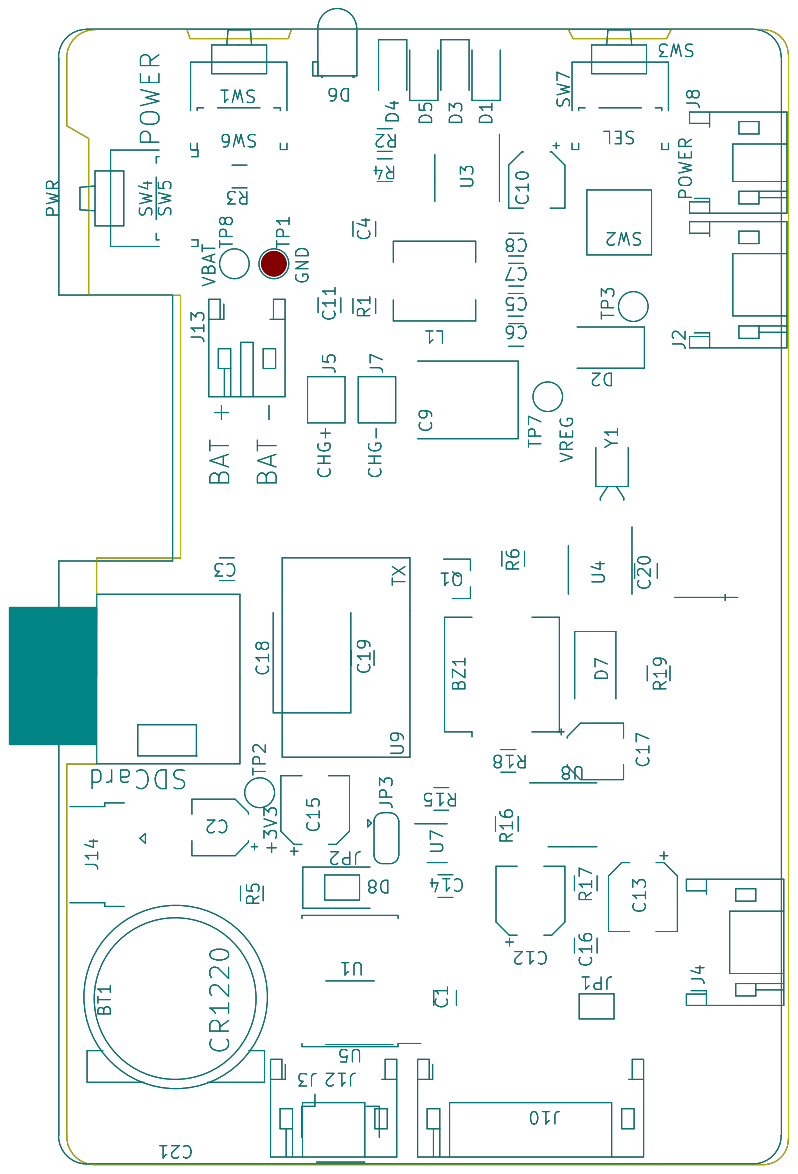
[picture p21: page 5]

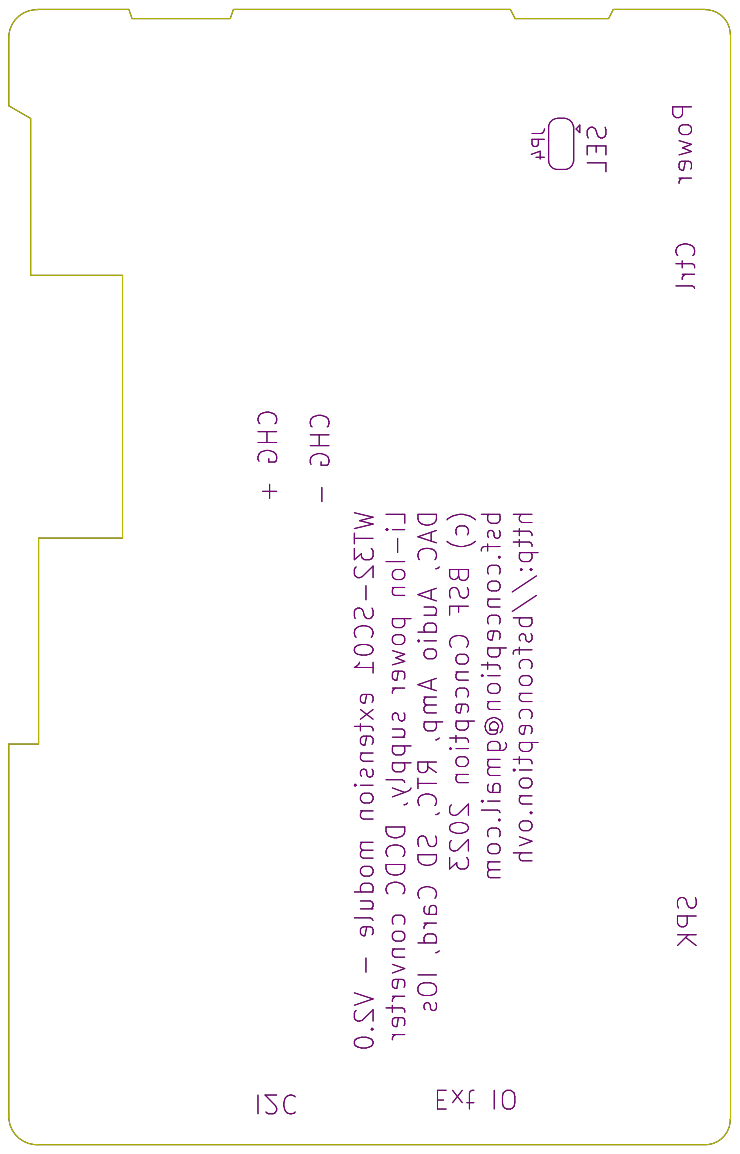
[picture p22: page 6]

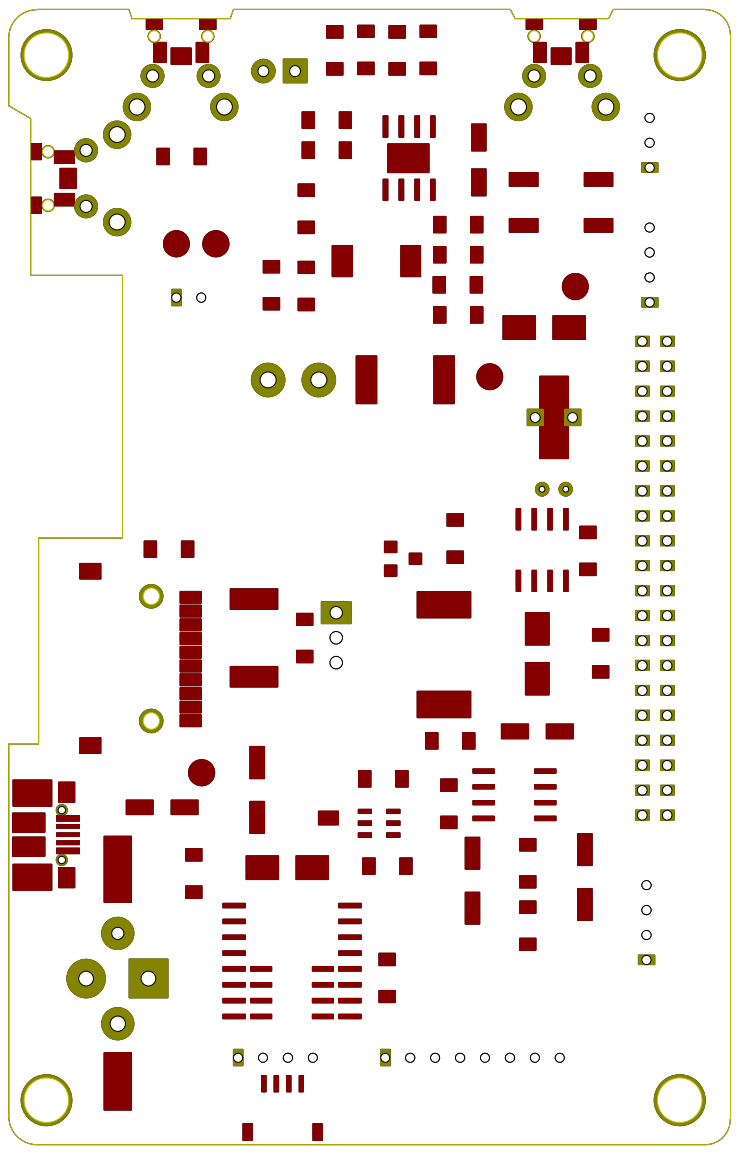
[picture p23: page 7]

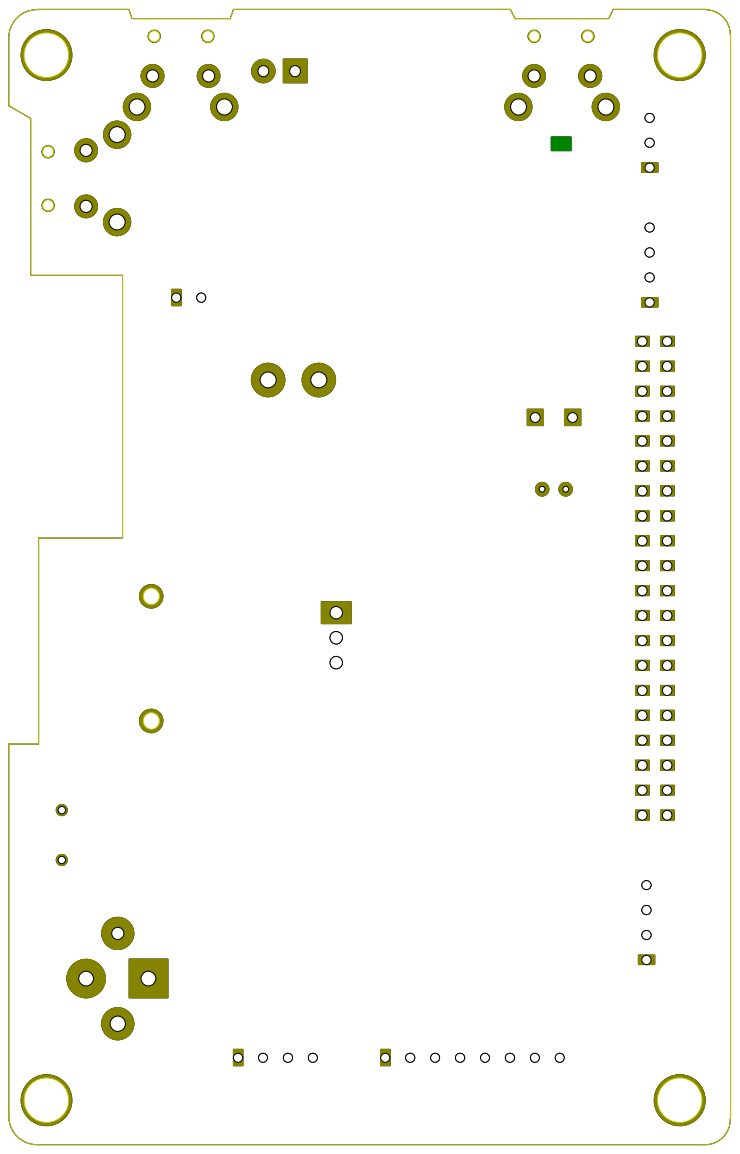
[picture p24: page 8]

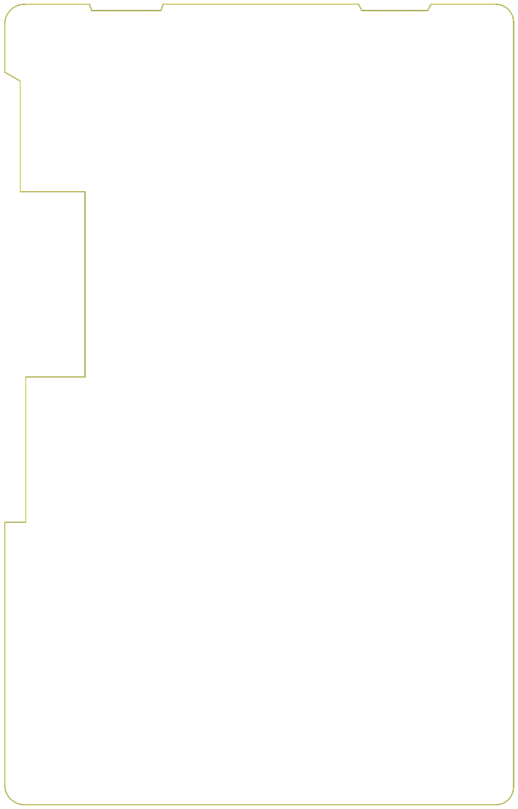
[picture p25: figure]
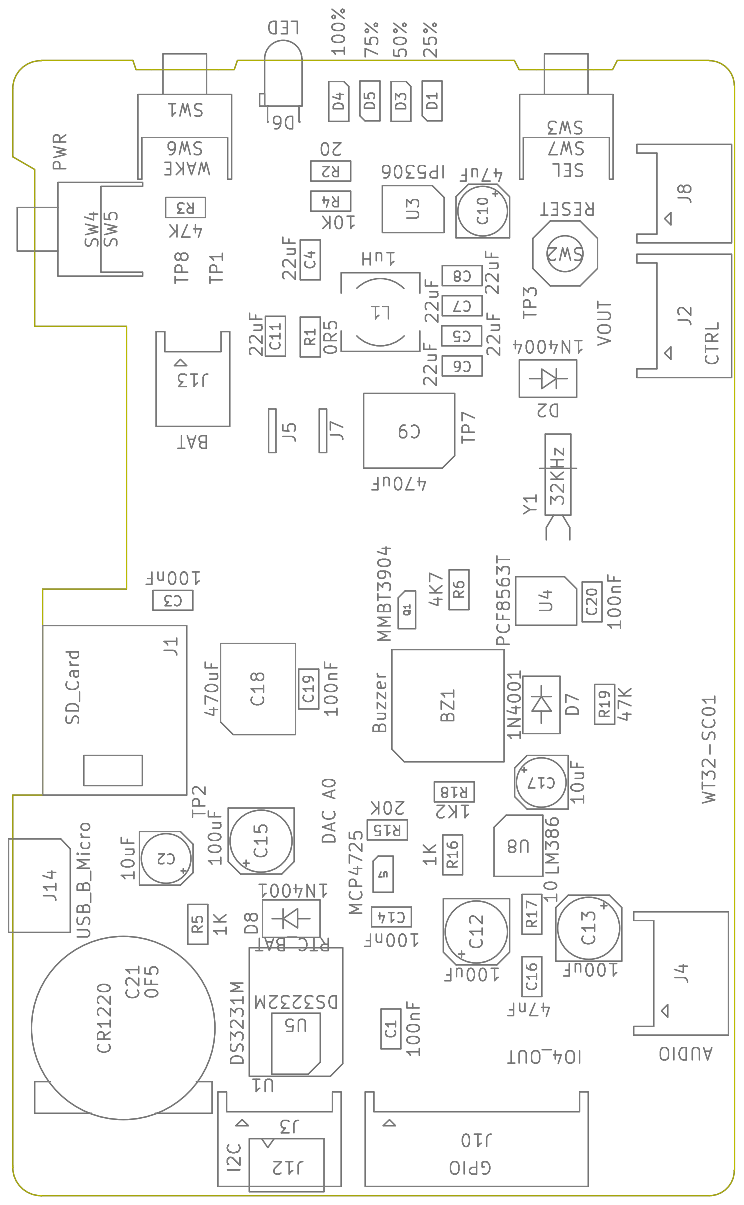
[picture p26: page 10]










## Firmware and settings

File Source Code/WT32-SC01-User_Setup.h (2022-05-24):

//                            USER DEFINED SETTINGS
//   Set driver type, fonts to be loaded, pins used and SPI control method etc
//
//   See the User_Setup_Select.h file if you wish to be able to define multiple
//   setups and then easily select which setup file is used by the compiler.
//
//   If this file is edited correctly then all the library example sketches should
//   run without the need to make any more changes for a particular hardware setup!
//   Note that some sketches are designed for a particular TFT pixel width/height


// ##################################################################################
//
// Section 1. Call up the right driver file and any options for it
//
// ##################################################################################

// Define STM32 to invoke optimised processor support (only for STM32)
//#define STM32

// Defining the STM32 board allows the library to optimise the performance
// for UNO compatible "MCUfriend" style shields
//#define NUCLEO_64_TFT
//#define NUCLEO_144_TFT

// STM32 8 bit parallel only:
// If STN32 Port A or B pins 0-7 are used for 8 bit parallel data bus bits 0-7
// then this will improve rendering performance by a factor of ~8x
//#define STM_PORTA_DATA_BUS
//#define STM_PORTB_DATA_BUS

// Tell the library to use 8 bit parallel mode (otherwise SPI is assumed)
//#define TFT_PARALLEL_8_BIT

// Display type -  only define if RPi display
//#define RPI_DISPLAY_TYPE // 20MHz maximum SPI

// Only define one driver, the other ones must be commented out
//#define ILI9341_DRIVER
//#define ST7735_DRIVER      // Define additional parameters below for this display
//#define ILI9163_DRIVER     // Define additional parameters below for this display
//#define S6D02A1_DRIVER
//#define RPI_ILI9486_DRIVER // 20MHz maximum SPI
//#define HX8357D_DRIVER
//#define ILI9481_DRIVER
//#define ILI9486_DRIVER
//#define ILI9488_DRIVER     // WARNING: Do not connect ILI9488 display SDO to MISO if other devices share the SPI bus (TFT SDO does NOT tristate when CS is high)
//#define ST7789_DRIVER      // Full configuration option, define additional parameters below for this display
//#define ST7789_2_DRIVER    // Minimal configuration option, define additional parameters below for this display
//#define R61581_DRIVER
//#define RM68140_DRIVER
#define ST7796_DRIVER
//#define SSD1963_480_DRIVER
//#define SSD1963_800_DRIVER
//#define SSD1963_800ALT_DRIVER
//#define ILI9225_DRIVER
//#define GC9A01_DRIVER

// Some displays support SPI reads via the MISO pin, other displays have a single
// bi-directional SDA pin and the library will try to read this via the MOSI line.
// To use the SDA line for reading data from the TFT uncomment the following line:

// #define TFT_SDA_READ      // This option is for ESP32 ONLY, tested with ST7789 and GC9A01 display only

// For ST7735, ST7789 and ILI9341 ONLY, define the colour order IF the blue and red are swapped on your display
// Try ONE option at a time to find the correct colour order for your display

//  #define TFT_RGB_ORDER TFT_RGB  // Colour order Red-Green-Blue
//  #define TFT_RGB_ORDER TFT_BGR  // Colour order Blue-Green-Red

// For M5Stack ESP32 module with integrated ILI9341 display ONLY, remove // in line below

// #define M5STACK

// For ST7789, ST7735, ILI9163 and GC9A01 ONLY, define the pixel width and height in portrait orientation
// #define TFT_WIDTH  80
// #define TFT_WIDTH  128
// #define TFT_WIDTH  240 // ST7789 240 x 240 and 240 x 320
// #define TFT_HEIGHT 160
// #define TFT_HEIGHT 128
// #define TFT_HEIGHT 240 // ST7789 240 x 240
// #define TFT_HEIGHT 320 // ST7789 240 x 320
// #define TFT_HEIGHT 240 // GC9A01 240 x 240

#define TFT_WIDTH  480
#define TFT_HEIGHT 320

#define DISPLAY_WIDTH  480
#define DISPLAY_HEIGHT 320

#define USE_HSPI_PORT 1
#define PIN_SDA 18
#define PIN_SCL 19
#define TFT_MISO 12
#define TFT_MOSI 13
#define TFT_SCLK 14
#define TFT_CS   15
#define TFT_DC   21
#define TFT_RST  22
#define TFT_BL   23

#define TOUCH_CS PIN_D2     // Chip select pin (T_CS) of touch screen


// For ST7735 ONLY, define the type of display, originally this was based on the
// colour of the tab on the screen protector film but this is not always true, so try
// out the different options below if the screen does not display graphics correctly,
// e.g. colours wrong, mirror images, or stray pixels at the edges.
// Comment out ALL BUT ONE of these options for a ST7735 display driver, save this
// this User_Setup file, then rebuild and upload the sketch to the board again:

// #define ST7735_INITB
// #define ST7735_GREENTAB
// #define ST7735_GREENTAB2
// #define ST7735_GREENTAB3
// #define ST7735_GREENTAB128    // For 128 x 128 display
// #define ST7735_GREENTAB160x80 // For 160 x 80 display (BGR, inverted, 26 offset)
// #define ST7735_REDTAB
// #define ST7735_BLACKTAB
// #define ST7735_REDTAB160x80   // For 160 x 80 display with 24 pixel offset

// If colours are inverted (white shows as black) then uncomment one of the next
// 2 lines try both options, one of the options should correct the inversion.

// #define TFT_INVERSION_ON
// #define TFT_INVERSION_OFF


// ##################################################################################
//
// Section 2. Define the pins that are used to interface with the display here
//
// ##################################################################################

// If a backlight control signal is available then define the TFT_BL pin in Section 2
// below. The backlight will be turned ON when tft.begin() is called, but the library
// needs to know if the LEDs are ON with the pin HIGH or LOW. If the LEDs are to be
// driven with a PWM signal or turned OFF/ON then this must be handled by the user
// sketch. e.g. with digitalWrite(TFT_BL, LOW);

// #define TFT_BL   32            // LED back-light control pin
// #define TFT_BACKLIGHT_ON HIGH  // Level to turn ON back-light (HIGH or LOW)
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

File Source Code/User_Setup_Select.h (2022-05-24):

// This header file contains a list of user setup files and defines which one the
// compiler uses when the IDE performs a Verify/Compile or Upload.
//
// Users can create configurations for different Espressif boards and TFT displays.
// This makes selecting between hardware setups easy by "uncommenting" one line.

// The advantage of this hardware configuration method is that the examples provided
// with the library should work with different setups immediately without any other
// changes being needed. It also improves the portability of users sketches to other
// hardware configurations and compatible libraries.
//
// Create a shortcut to this file on your desktop to permit quick access for editing.
// Re-compile and upload after making and saving any changes to this file.

// Customised User_Setup files are stored in the "User_Setups" folder.

#ifndef USER_SETUP_LOADED //  Lets PlatformIO users define settings in
                          //  platformio.ini, see notes in "Tools" folder.

// Only ONE line below should be uncommented.  Add extra lines and files as needed.

//#include <User_Setup.h>           // Default setup is root library folder
//#include <SmartHub.h>   // smart hub
#include <WT32-SC01-User_Setup.h>

//#include <User_Setups/Setup1_ILI9341.h>  // Setup file configured for my ILI9341
//#include <User_Setups/Setup2_ST7735.h>   // Setup file configured for my ST7735
//#include <User_Setups/Setup3_ILI9163.h>  // Setup file configured for my ILI9163
//#include <User_Setups/Setup4_S6D02A1.h>  // Setup file configured for my S6D02A1
//#include <User_Setups/Setup5_RPi_ILI9486.h>        // Setup file configured for my stock RPi TFT
//#include <User_Setups/Setup6_RPi_Wr_ILI9486.h>     // Setup file configured for my modified RPi TFT
//#include <User_Setups/Setup7_ST7735_128x128.h>     // Setup file configured for my ST7735 128x128 display
//#include <User_Setups/Setup8_ILI9163_128x128.h>    // Setup file configured for my ILI9163 128x128 display
//#include <User_Setups/Setup9_ST7735_Overlap.h>     // Setup file configured for my ST7735
//#include <User_Setups/Setup10_RPi_touch_ILI9486.h> // Setup file configured for ESP8266 and RPi TFT with touch

//#include <User_Setups/Setup11_RPi_touch_ILI9486.h> // Setup file configured for ESP32 and RPi TFT with touch
//#include <User_Setups/Setup12_M5Stack.h>           // Setup file for the ESP32 based M5Stack
//#include <User_Setups/Setup13_ILI9481_Parallel.h>  // Setup file for the ESP32 with parallel bus TFT
//#include <User_Setups/Setup14_ILI9341_Parallel.h>  // Setup file for the ESP32 with parallel bus TFT
//#include <User_Setups/Setup15_HX8357D.h>           // Setup file configured for HX8357D (untested)
//#include <User_Setups/Setup16_ILI9488_Parallel.h>  // Setup file for the ESP32 with parallel bus TFT
//#include <User_Setups/Setup17_ePaper.h>            // Setup file for any Waveshare ePaper display
//#include <User_Setups/Setup18_ST7789.h>            // Setup file configured for ST7789

//#include <User_Setups/Setup19_RM68140_Parallel.h>	 // Setup file configured for RM68140 with parallel bus

//#include <User_Setups/Setup20_ILI9488.h>           // Setup file for ESP8266 and ILI9488 SPI bus TFT
//#include <User_Setups/Setup21_ILI9488.h>           // Setup file for ESP32 and ILI9488 SPI bus TFT

//#include <User_Setups/Setup22_TTGO_T4.h>           // Setup file for ESP32 and TTGO T4 version 1.2
//#include <User_Setups/Setup22_TTGO_T4_v1.3.h>      // Setup file for ESP32 and TTGO T4 version 1.3
//#include <User_Setups/Setup23_TTGO_TM.h>           // Setup file for ESP32 and TTGO TM ST7789 SPI bus TFT
//#include <User_Setups/Setup24_ST7789.h>            // Setup file configured for ST7789 240 x 240
//#include <User_Setups/Setup25_TTGO_T_Display.h>    // Setup file for ESP32 and TTGO T-Display ST7789V SPI bus TFT
//#include <User_Setups/Setup26_TTGO_T_Wristband.h>  // Setup file for ESP32 and TTGO T-Wristband ST7735 SPI bus TFT

//#include <User_Setups/Setup27_RPi_ST7796_ESP32.h>    // ESP32   RPi MHS-4.0 inch Display-B
//#include <User_Setups/Setup28_RPi_ST7796_ESP8266.h>  // ESP8266 RPi MHS-4.0 inch Display-B

//#include <User_Setups/Setup29_ILI9341_STM32.h>          // Setup for Nucleo board
//#include <User_Setups/Setup30_ILI9341_Parallel_STM32.h> // Setup for Nucleo board and parallel display
//#include <User_Setups/Setup31_ST7796_Parallel_STM32.h>  // Setup for Nucleo board and parallel display
//#include <User_Setups/Setup32_ILI9341_STM32F103.h>      // Setup for "Blue/Black Pill"

//#include <User_Setups/Setup33_RPi_ILI9486_STM32.h>      // Setup for Nucleo board

//#include <User_Setups/Setup34_ILI9481_Parallel_STM32.h> // Setup for Nucleo board and parallel display
//#include <User_Setups/Setup35_ILI9341_STM32_Port_Bus.h> // Setup for STM32 port A parallel display

//#include <User_Setups/Setup36_RPi_touch_ST7796.h>      // Setup file configured for ESP32 and RPi ST7796 TFT with touch

//#include <User_Setups/Setup43_ST7735.h>            // Setup file configured for my ST7735S 80x160
//#include <User_Setups/Setup44_TTGO_CameraPlus.h>   // Setup file for ESP32 and TTGO T-CameraPlus ST7789 SPI bus TFT    240x240
//#include <User_Setups/Setup45_TTGO_T_Watch.h>      // Setup file for ESP32 and TTGO T-Watch ST7789 SPI bus TFT  240x240

//#include <User_Setups/Setup47_ST7735.h>            // Setup file configured for ST7735 128 x 128 animated eyes

//#include <User_Setups/Setup50_SSD1963_Parallel.h>  // Setup file for ESP32 and SSD1963 TFT display

//#include <User_Setups/Setup51_LilyPi_ILI9481.h>    // Setup file for LilyGo LilyPi with ILI9481 display
//#include <User_Setups/Setup52_LilyPi_ST7796.h>     // Setup file for LilyGo LilyPi with ST7796 display

//#include <User_Setups/Setup60_RP2040_ILI9341.h>    // Setup file for RP2040 with SPI ILI9341
//#include <User_Setups/Setup61_RP2040_ILI9341_PIO_SPI.h>    // Setup file for RP2040 with PIO SPI ILI9341
//#include <User_Setups/Setup62_RP2040_Nano_Connect_ILI9341.h>    // Setup file for RP2040 with SPI ILI9341

//#include <User_Setups/Setup70_ESP32_S2_ILI9341.h>  // Setup file for ESP32 S2 with SPI ILI9341

//#include <User_Setups/Setup71_ESP32_S2_ST7789.h>  // Setup file for ESP32 S2 with ST7789

//#include <User_Setups/Setup100_RP2040_ILI9488_parallel.h>
//#include <User_Setups/Setup101_RP2040_ILI9481_parallel.h>
//#include <User_Setups/Setup102_RP2040_ILI9341_parallel.h>
//#include <User_Setups/Setup103_RP2040_ILI9486_parallel.h>
//#include <User_Setups/Setup104_RP2040_ST7796_parallel.h>
//#include <User_Setups/Setup105_RP2040_ILI9341_PIO_SPI.h>    // Setup file for Raspberry Pi Pico with SPI PIO interface and ILI9341

//#include <User_Setups/Setup135_ST7789.h>           // Setup file for ESP8266 and ST7789 135 x 240 TFT
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

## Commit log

2022-06-09 Moved to V1.0 subfolder
    Moved to V1.0 subfolder
    [WT32_1_corr.stl, WT32_2_corr.stl, WT32_3_corr.stl]
2022-06-09 Moving to V1.0 subfolders
    [WT32-SC01.BOM.csv]
2022-07-05 V1.1
    Adding V1.1 version
    [WT32-SC01.V1.1.BOM.csv]
2022-07-08 I2C Init correction
    Correction of the I2C Init that sometimes went wronf
    Adding option to manage the V1.1 board (SEL burton level set by a jumper)
    [DAC.ino, GUI.ino, Global_Settings.h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]
2022-07-14 New box
    [WT_a.stl, WT_b.stl, WT_c.stl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]
2022-07-14 Adding solution enclosure
2022-08-17 Update files
    [WT32-SC01.V1.2.CSV, WT32-SC01.V1.2_BOM.CSV]
2023-02-18 Update for PCB V2.0
    Add PCF8563 RTC
    Correct Touch screen issues
    [DAC.ino, GUI.ino, Global_Settings.h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]
